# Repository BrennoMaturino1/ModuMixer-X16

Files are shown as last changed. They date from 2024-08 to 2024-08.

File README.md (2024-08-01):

# ModuMixer X16
ModuMixer is a modular digital audio mixer project with an almost unlimited amount of input and output channels (the limit is 65536)
It can be customized with input or output modules that are recognized by the "main computer"
The cue and main output signals are connected together in a summing amplifier configuration where each module sums it's signal to the data lines
The modules are digitally recognized by a custom protocol over USART where during boot one module is powered at a time and receives an address from the main computer (i know connecting multiple devices to USART isn't a good idea but i guess it will work), the digital signal processing works with an STM32 microcontroller for processing and a codec for digital to analog and analog to digital conversions

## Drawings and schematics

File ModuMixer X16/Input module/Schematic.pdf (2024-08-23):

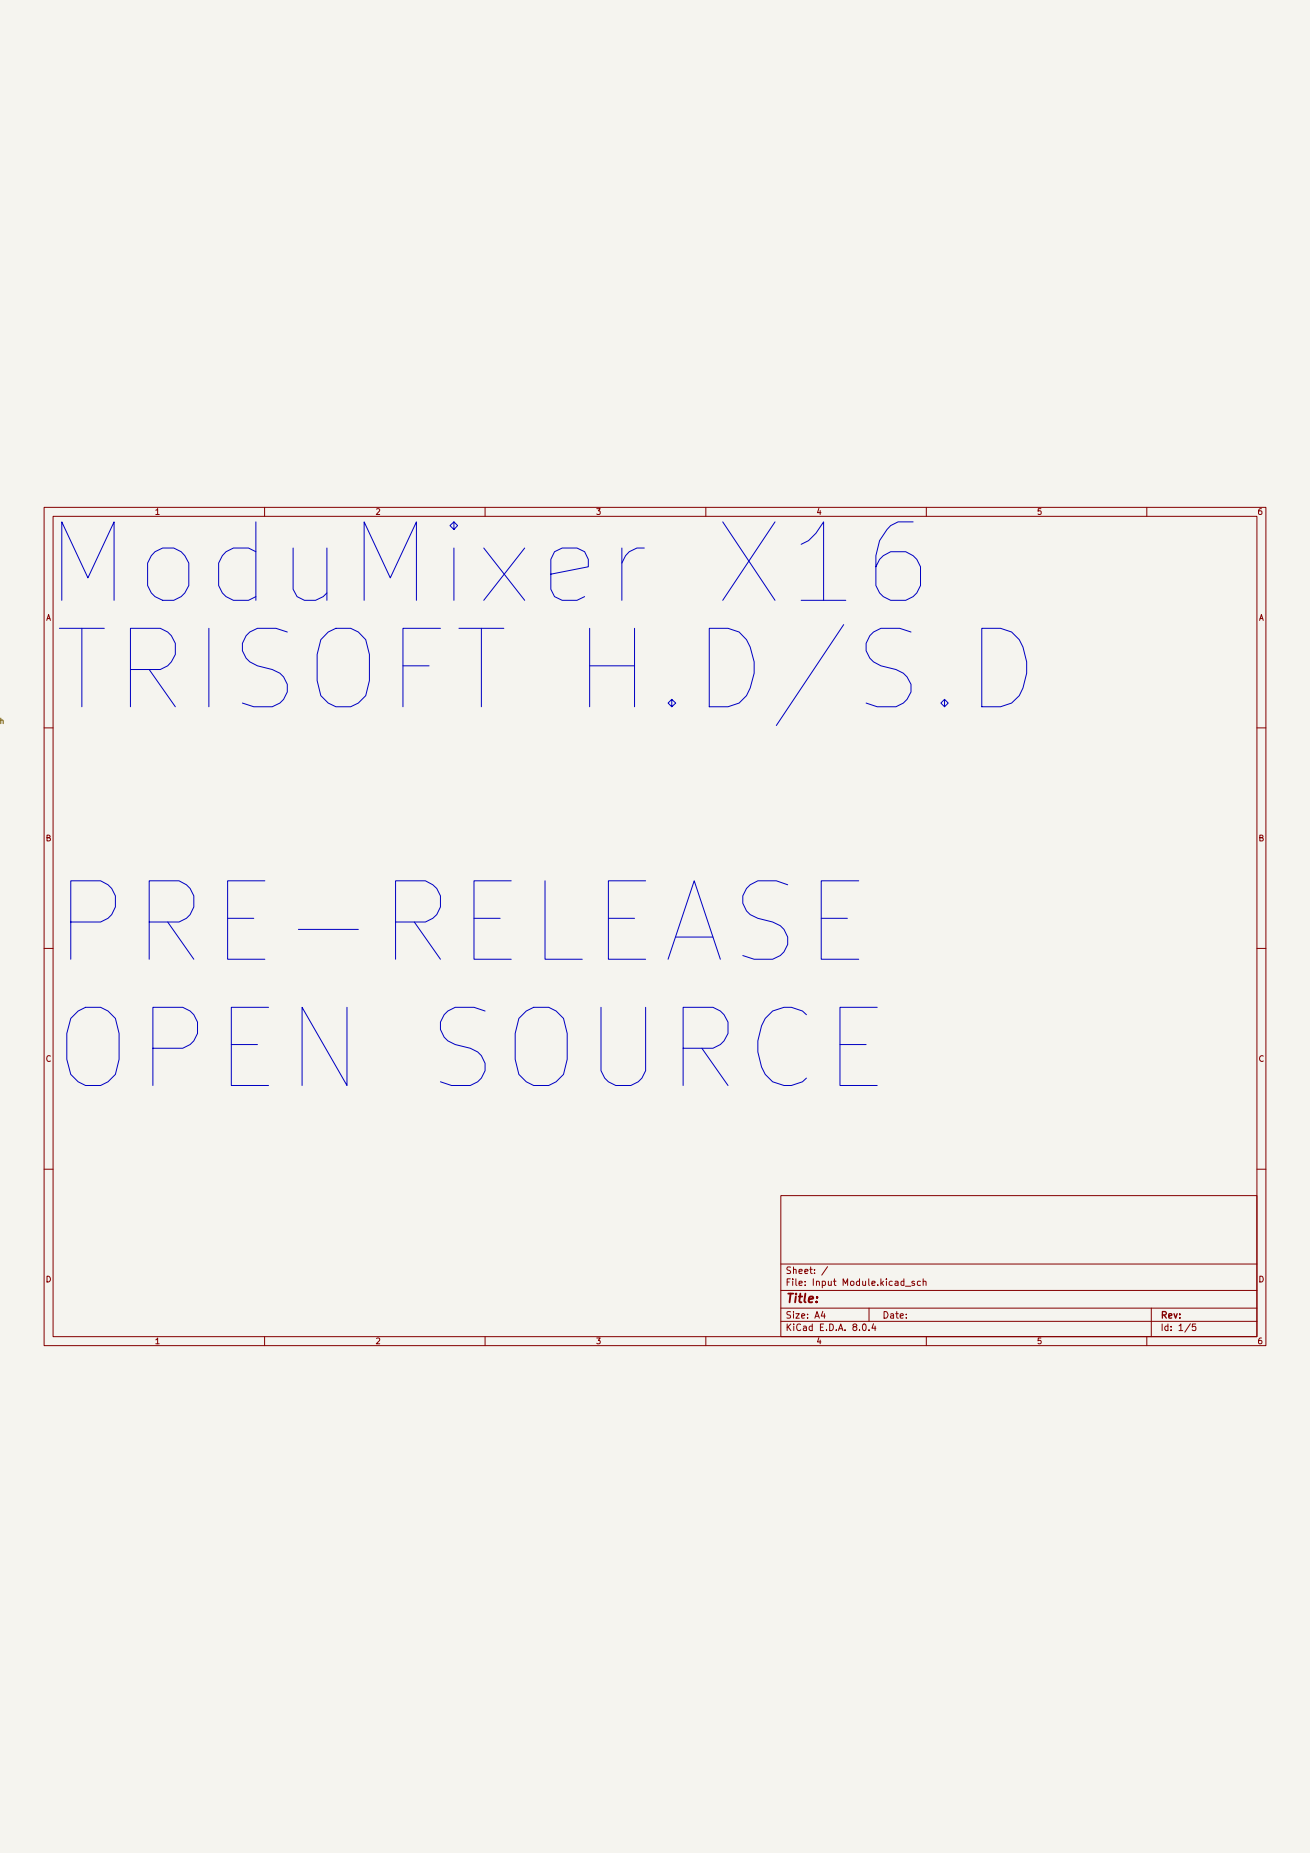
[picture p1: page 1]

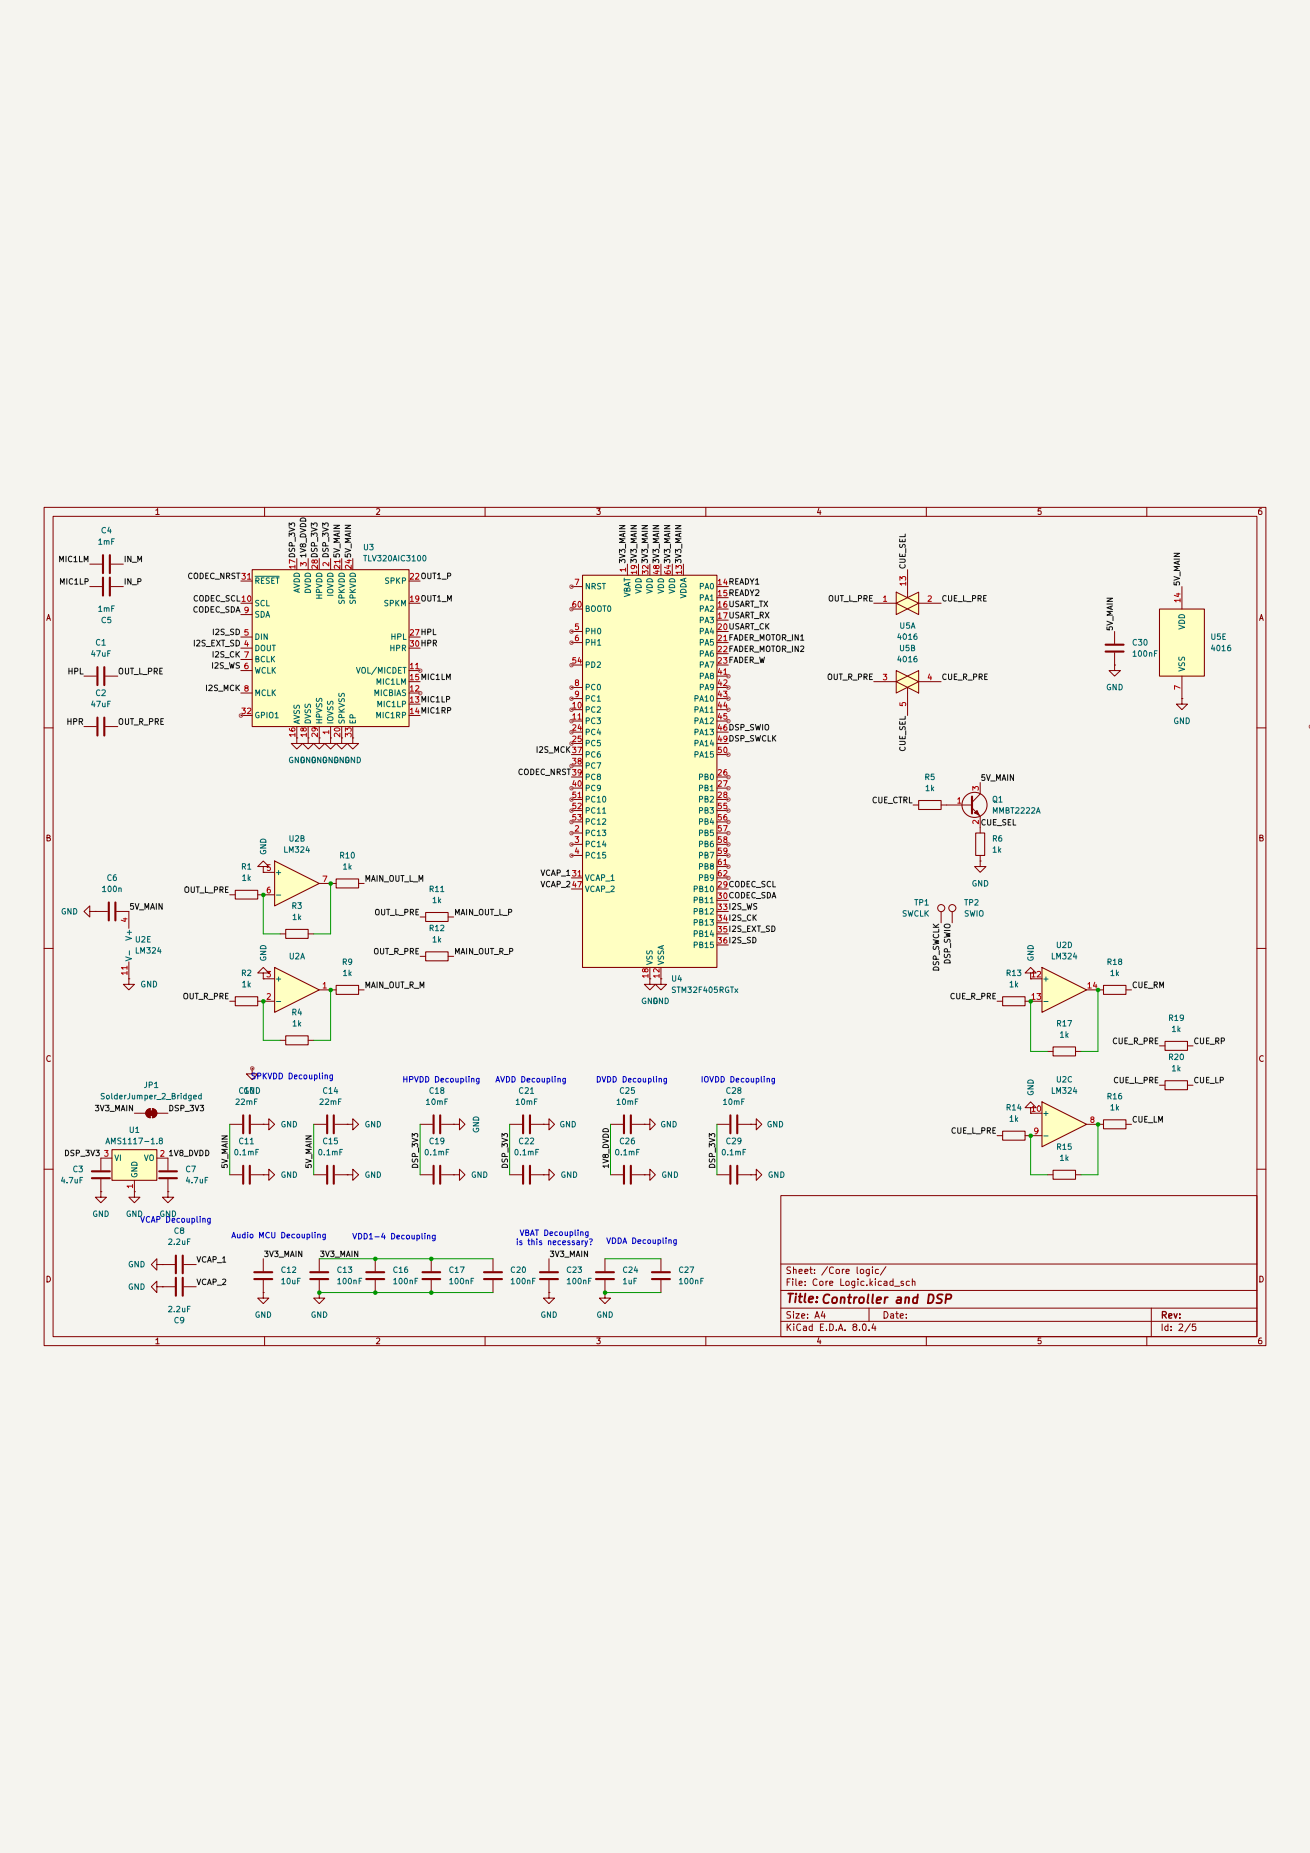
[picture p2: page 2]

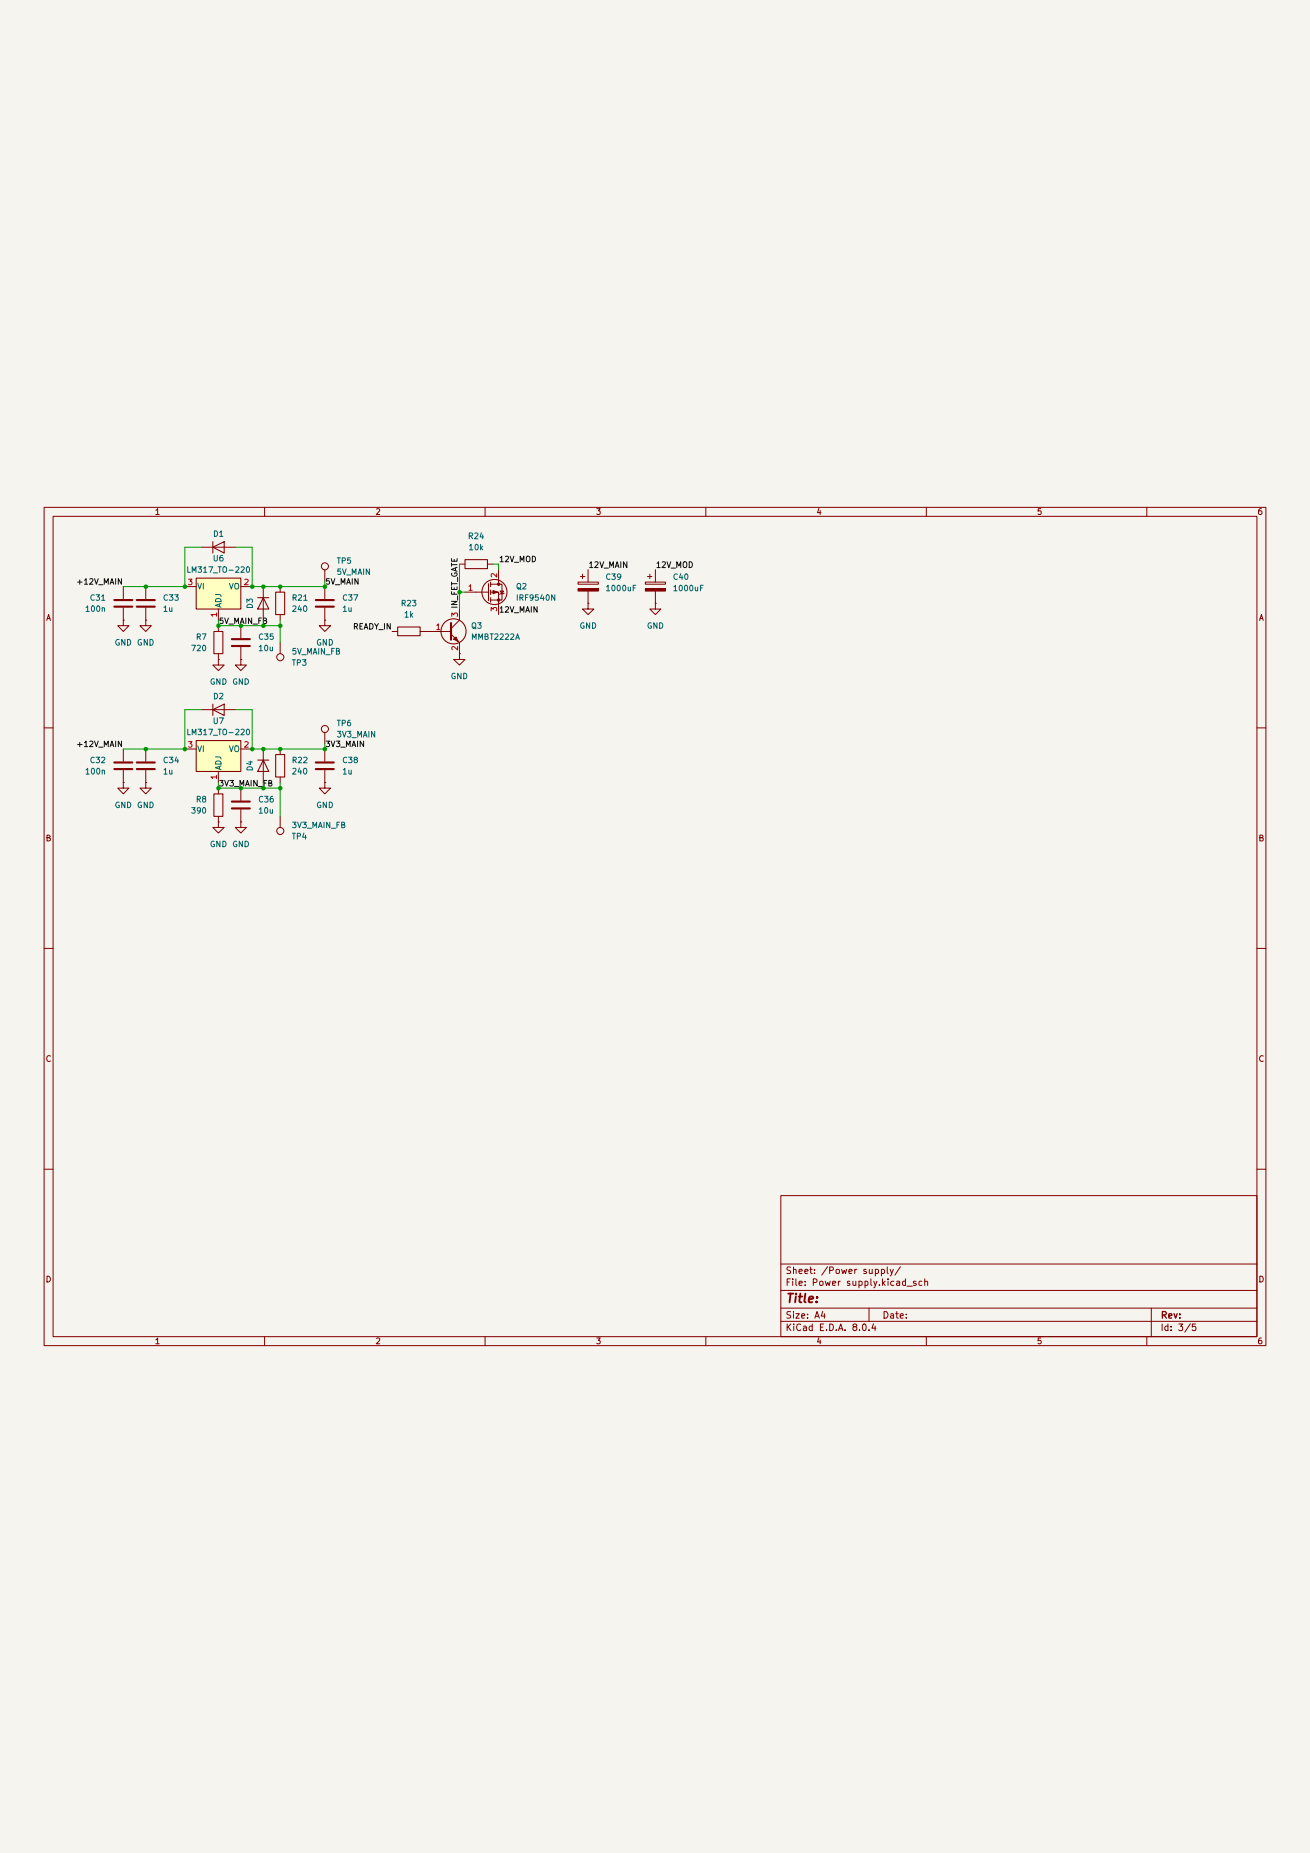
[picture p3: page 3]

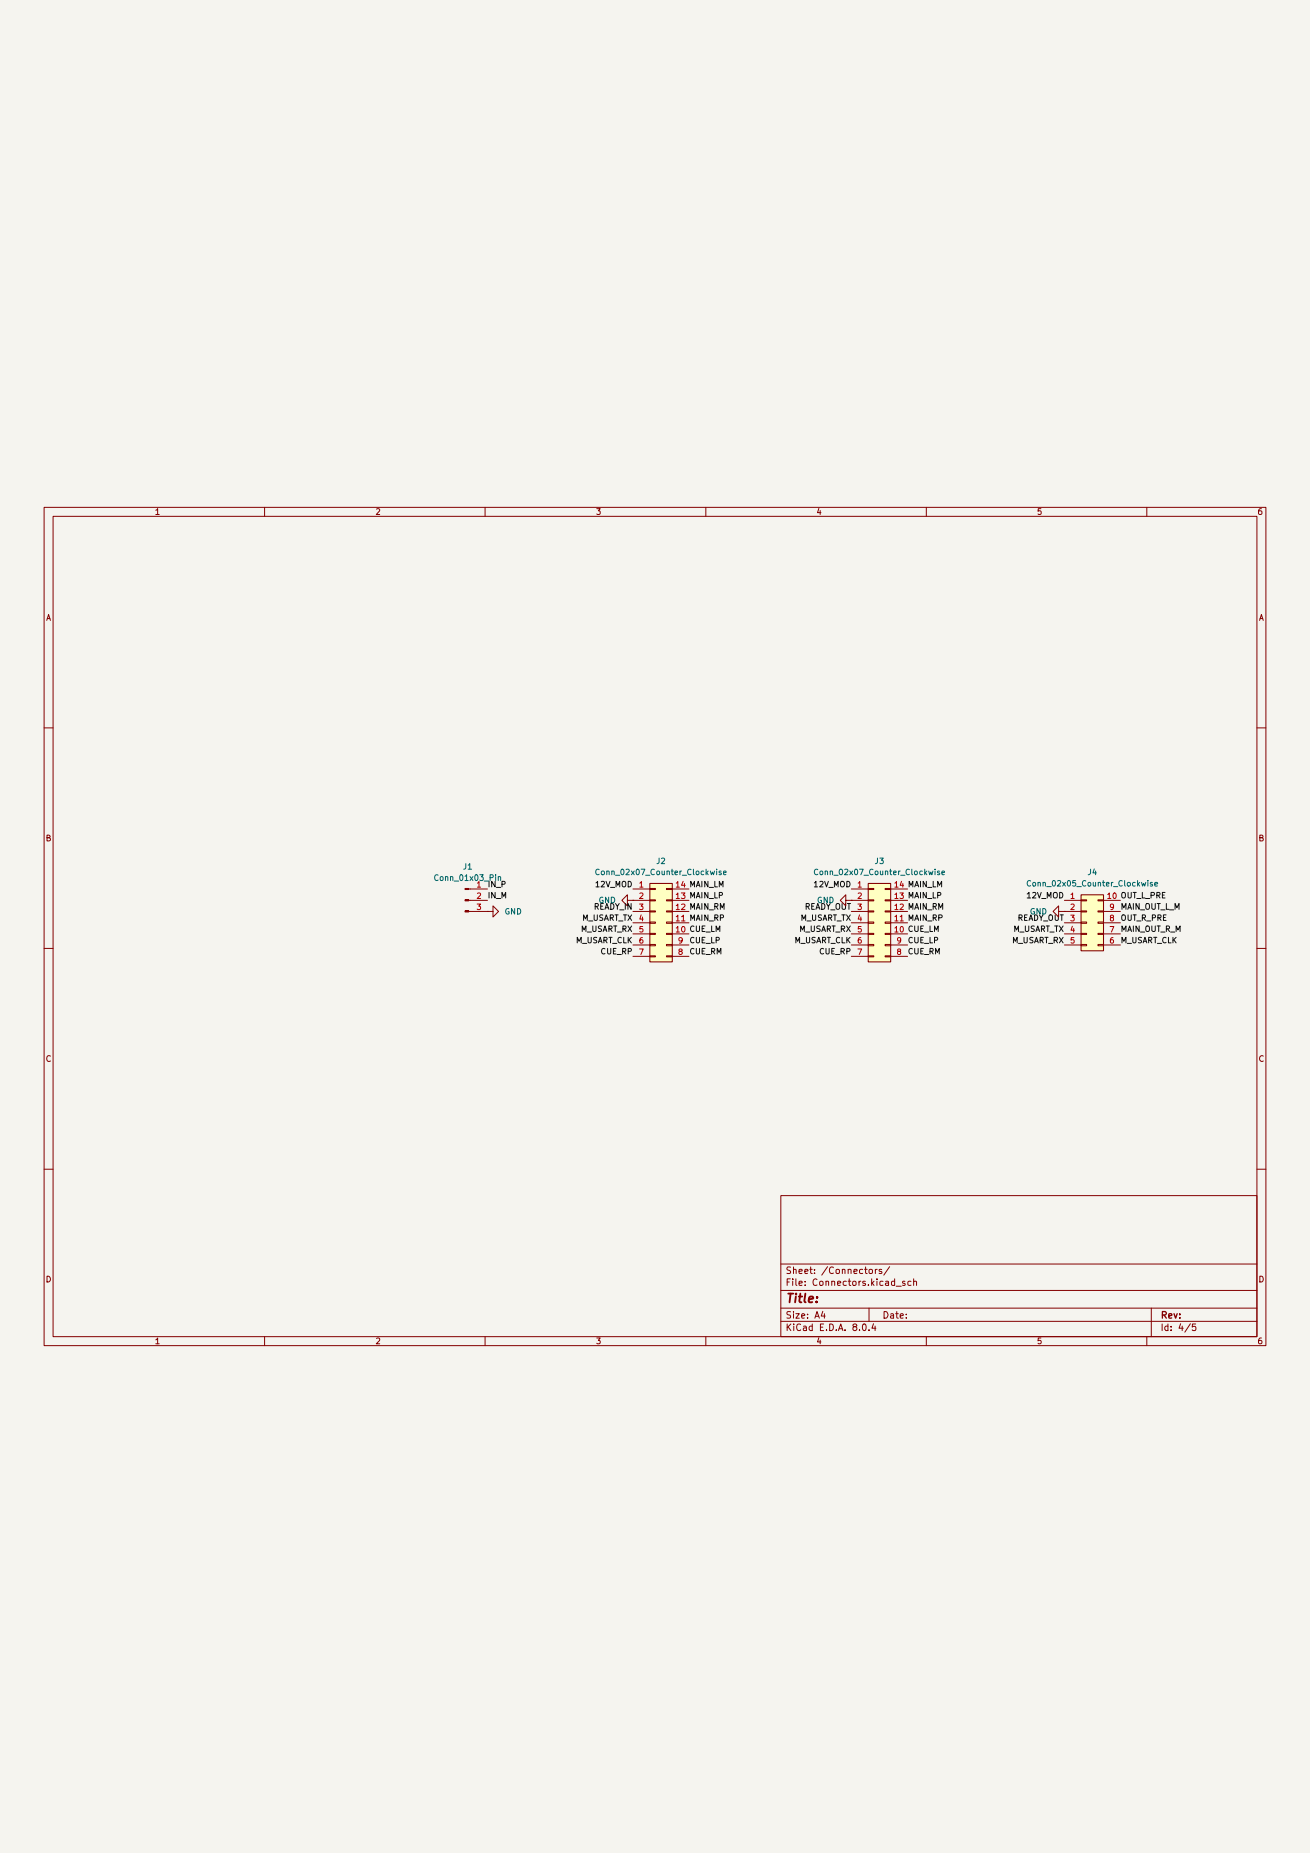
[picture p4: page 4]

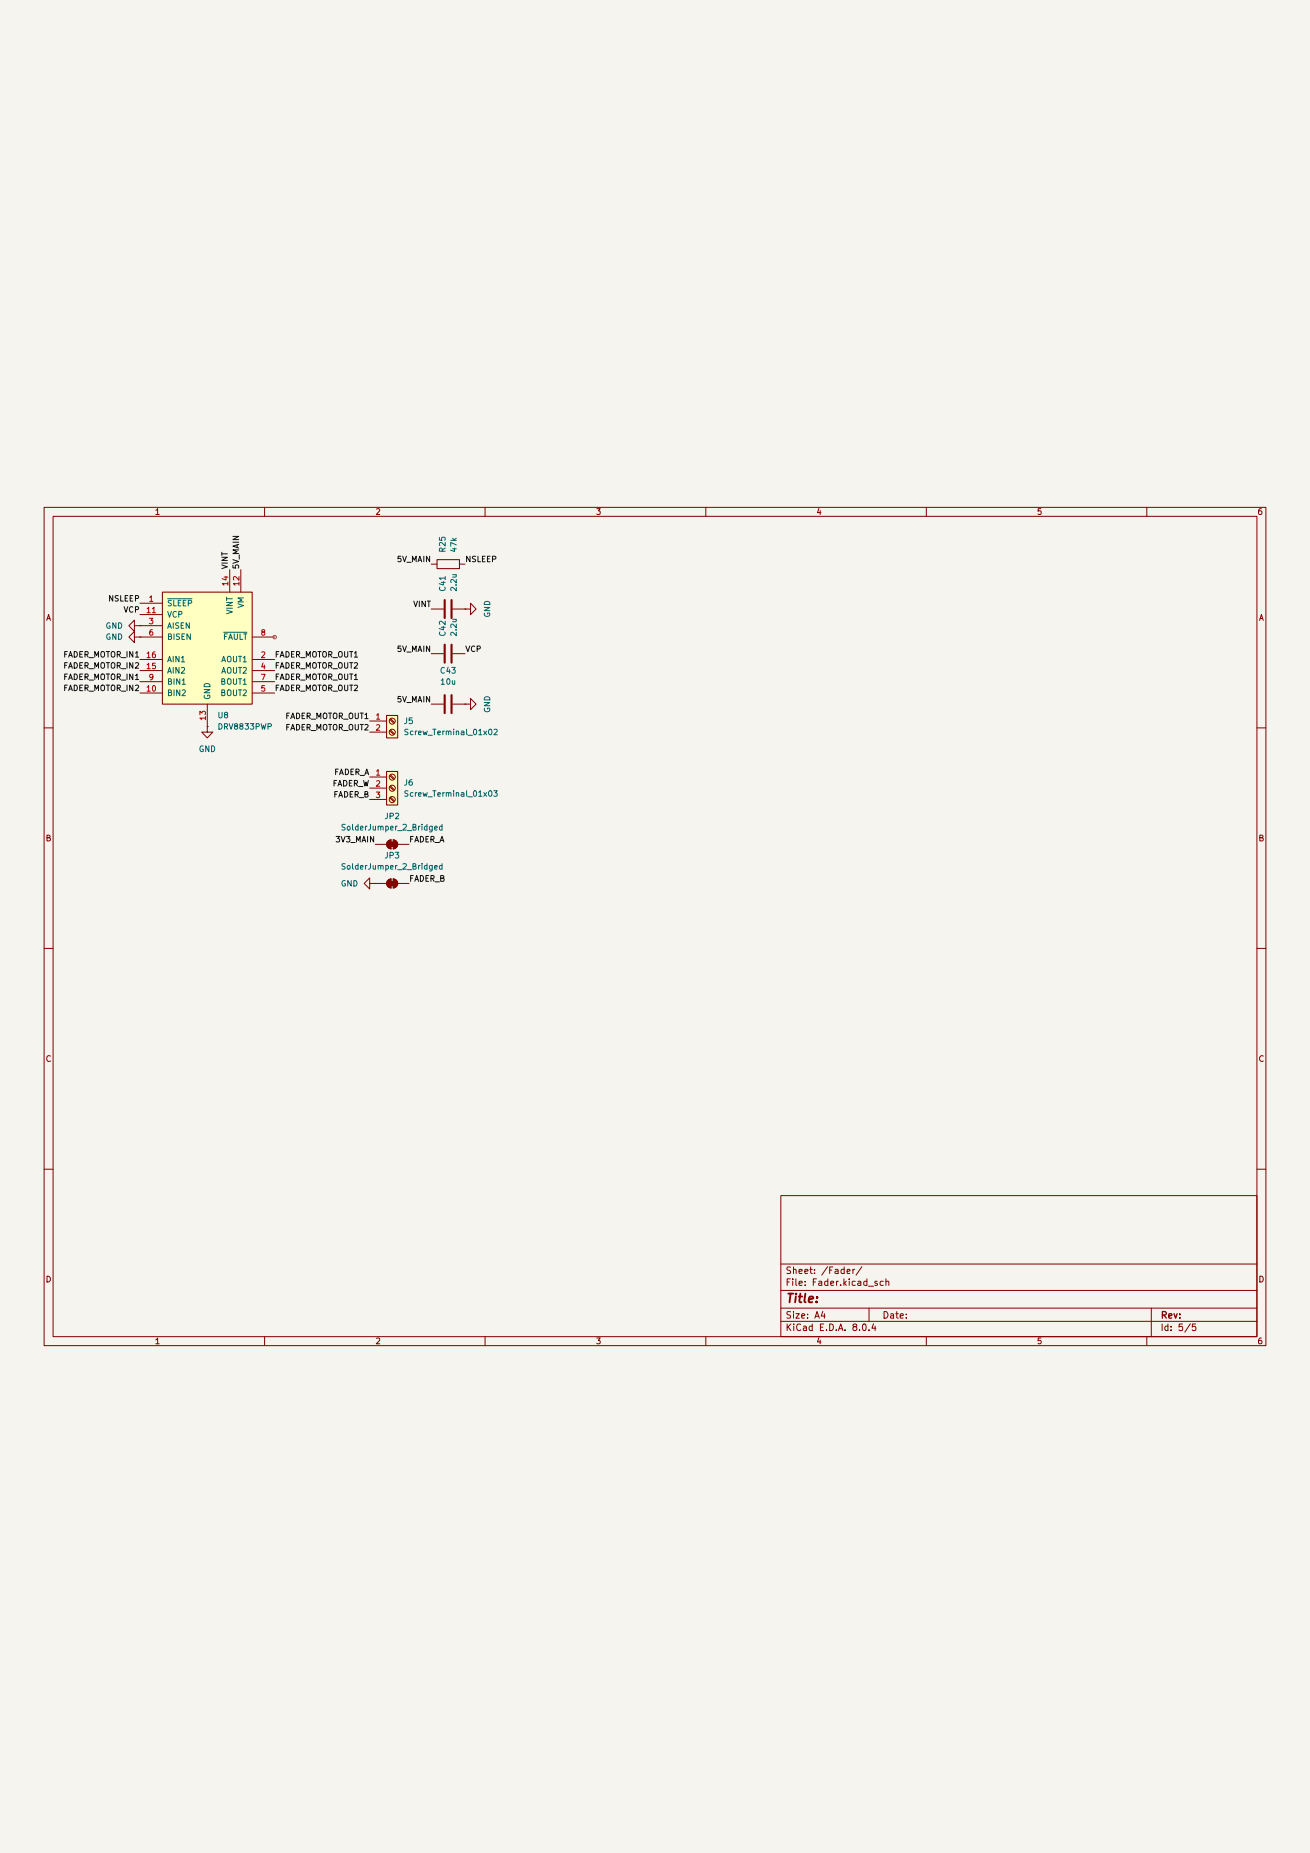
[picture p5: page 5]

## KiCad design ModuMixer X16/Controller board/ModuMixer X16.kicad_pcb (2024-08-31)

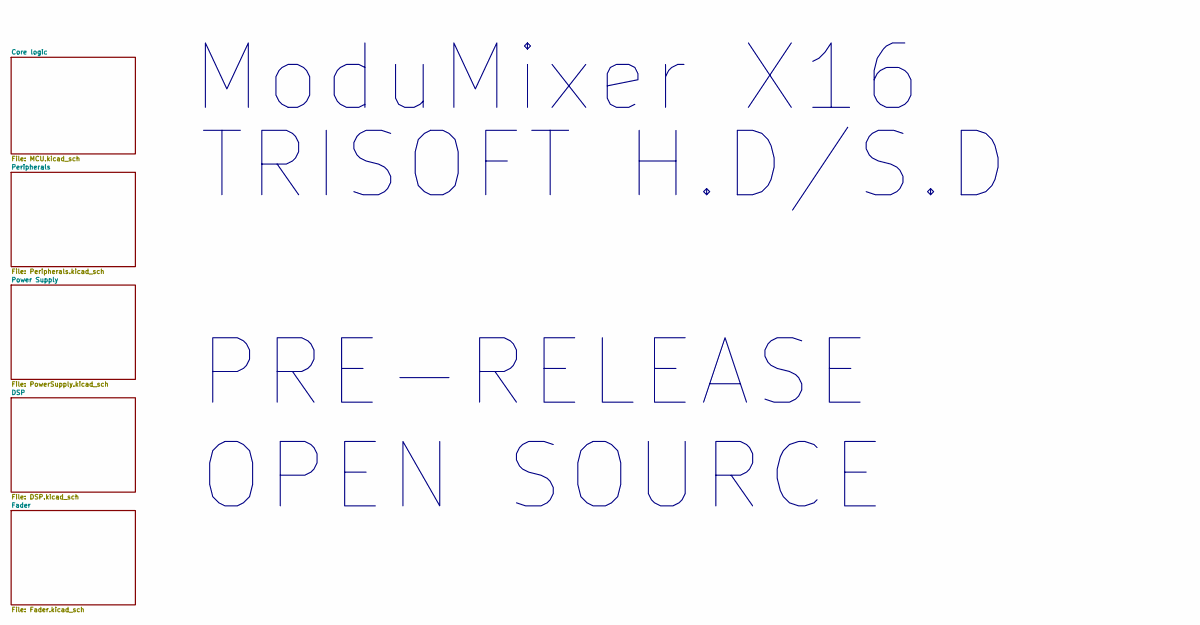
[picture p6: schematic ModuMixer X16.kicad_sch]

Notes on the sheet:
ModuMixer X16
TRISOFT H.D/S.D PRE-RELEASE OPEN SOURCE

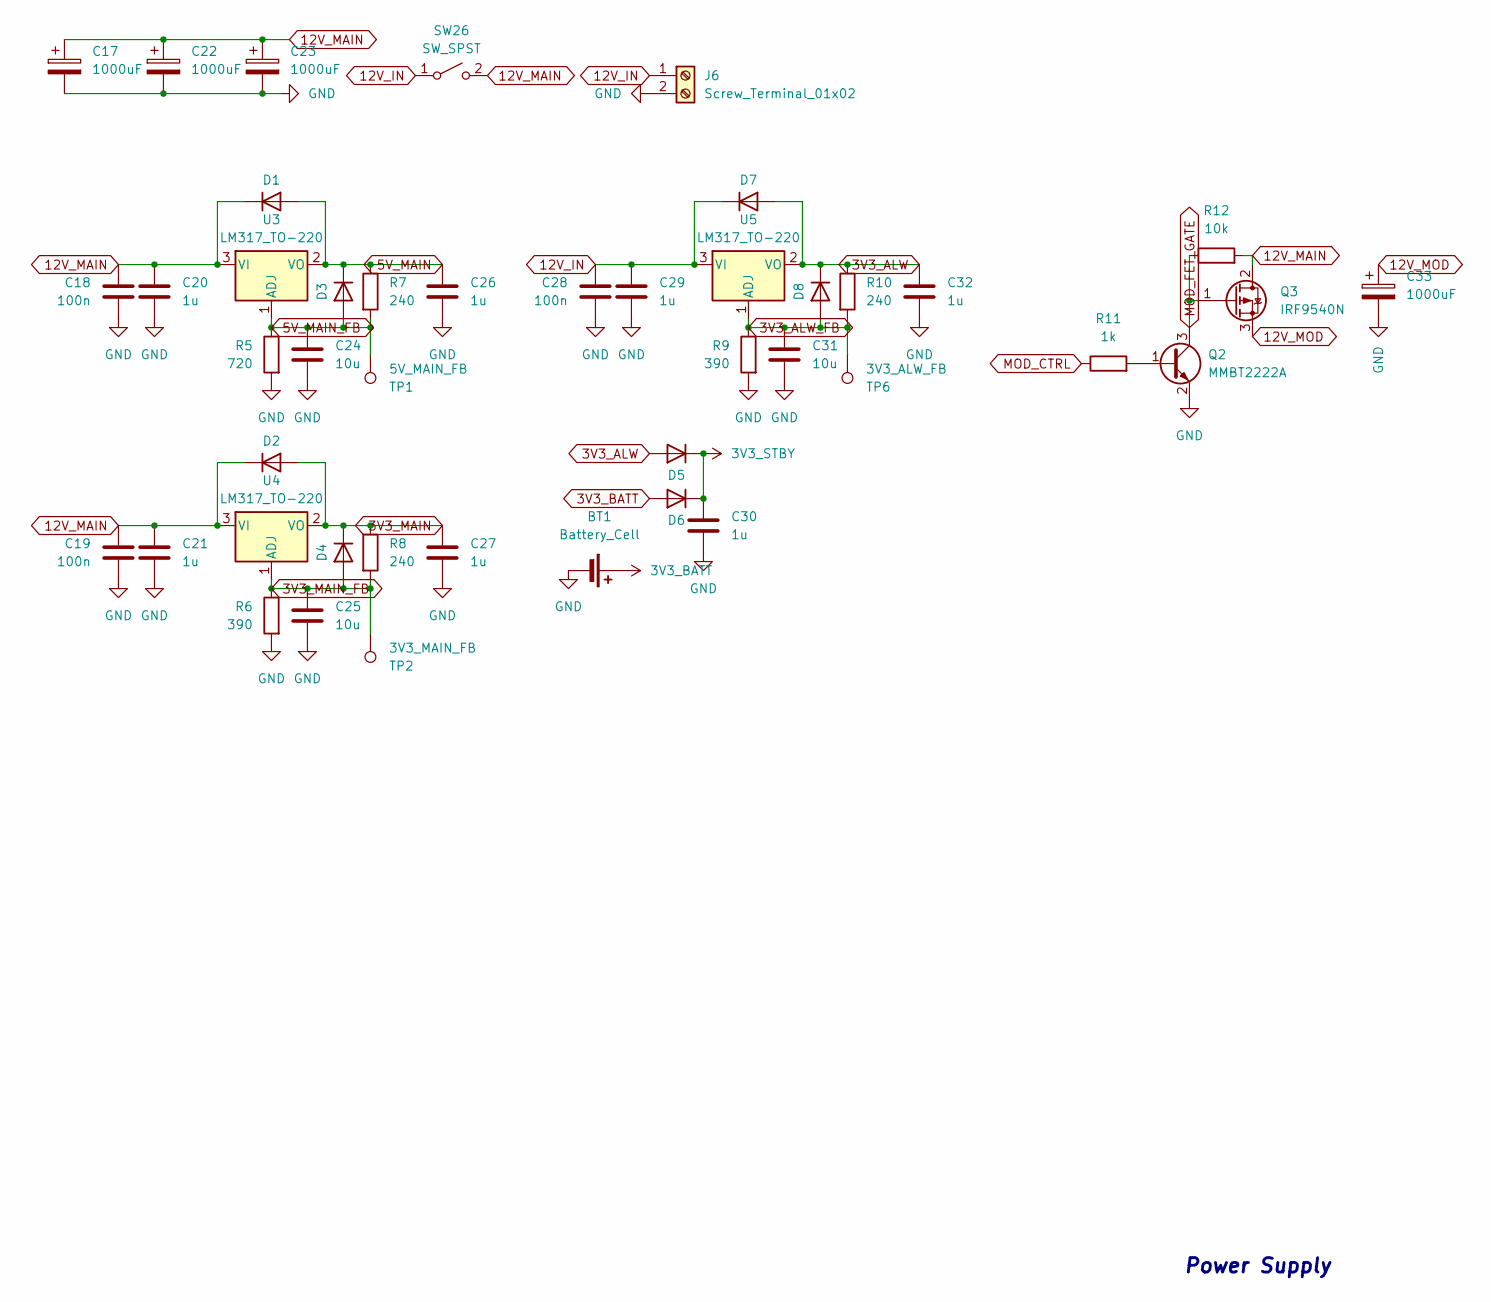
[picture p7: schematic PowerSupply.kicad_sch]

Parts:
BT1: Battery_Cell
C17, C22, C23, C33: 1000uF; CP_Elec_10x10
C18, C19, C28: 100n; C_0603_1608Metric
C20, C21, C26, C27, C29, C30, C32: 1u; C_0603_1608Metric
C24, C25, C31: 10u; C_0603_1608Metric
D1, D2, D3, D4, D5, D6, D7, D8: D_SOD-123
J6: Screw_Terminal_01x02; TerminalBlock_Xinya_XY308-2.54-2P_1x02_P2.54mm_Horizontal
Q2: MMBT2222A; SOT-23
Q3: IRF9540N; TO-220-3_Vertical
R5: 720; R_0603_1608Metric
R6, R9: 390; R_0603_1608Metric
R7, R8, R10: 240; R_0603_1608Metric
R11: 1k; R_0603_1608Metric
R12: 10k; R_0603_1608Metric
SW26: SW_SPST; TerminalBlock_Xinya_XY308-2.54-2P_1x02_P2.54mm_Horizontal
TP1: 5V_MAIN_FB; TestPoint_Pad_D3.0mm
TP2: 3V3_MAIN_FB; TestPoint_Pad_D3.0mm
TP6: 3V3_ALW_FB; TestPoint_Pad_D3.0mm
U3, U4, U5: LM317_TO-220; TO-220-3_Vertical

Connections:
3V3_ALW: C32.1, D5.2 (A), D7.2 (A), D8.1 (K), R10.1, U5.2 (VO)
3V3_ALW_FB: C31.1, D8.2 (A), R9.1, R10.2, TP6.1, U5.1 (ADJ)
3V3_BATT: D6.2 (A)
3V3_MAIN: C27.1, D2.2 (A), D4.1 (K), R8.1, U4.2 (VO); also elsewhere on the board
3V3_MAIN_FB: C25.1, D4.2 (A), R6.1, R8.2, TP2.1, U4.1 (ADJ)
3V3_STBY: C30.1, D5.1 (K), D6.1 (K); also elsewhere on the board
5V_MAIN: C26.1, D1.2 (A), D3.1 (K), R7.1, U3.2 (VO); also elsewhere on the board
5V_MAIN_FB: C24.1, D3.2 (A), R5.1, R7.2, TP1.1, U3.1 (ADJ)
12V_IN: C28.1, C29.1, D7.1 (K), J6.1, SW26.1 (A), U5.3 (VI)
12V_MAIN: C17.1, C18.1, C19.1, C20.1, C21.1, C22.1, C23.1, D1.1 (K), D2.1 (K), Q3.2 (D), R12.2, SW26.2 (B), U3.3 (VI), U4.3 (VI)
12V_MOD: C33.1, Q3.3 (S); also elsewhere on the board
GND: BT1.2 (-), C17.2, C18.2, C19.2, C20.2, C21.2, C22.2, C23.2, C24.2, C25.2, C26.2, C27.2, C28.2, C29.2, C30.2, C31.2, C32.2, C33.2, J6.2, Q2.2 (E), R5.2, R6.2, R9.2; also elsewhere on the board
MOD_CTRL: R11.1; also elsewhere on the board
MOD_FET_GATE: Q2.3 (C), Q3.1 (G), R12.1
unnamed: Q2.1 (B), R11.2

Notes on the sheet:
Power Supply

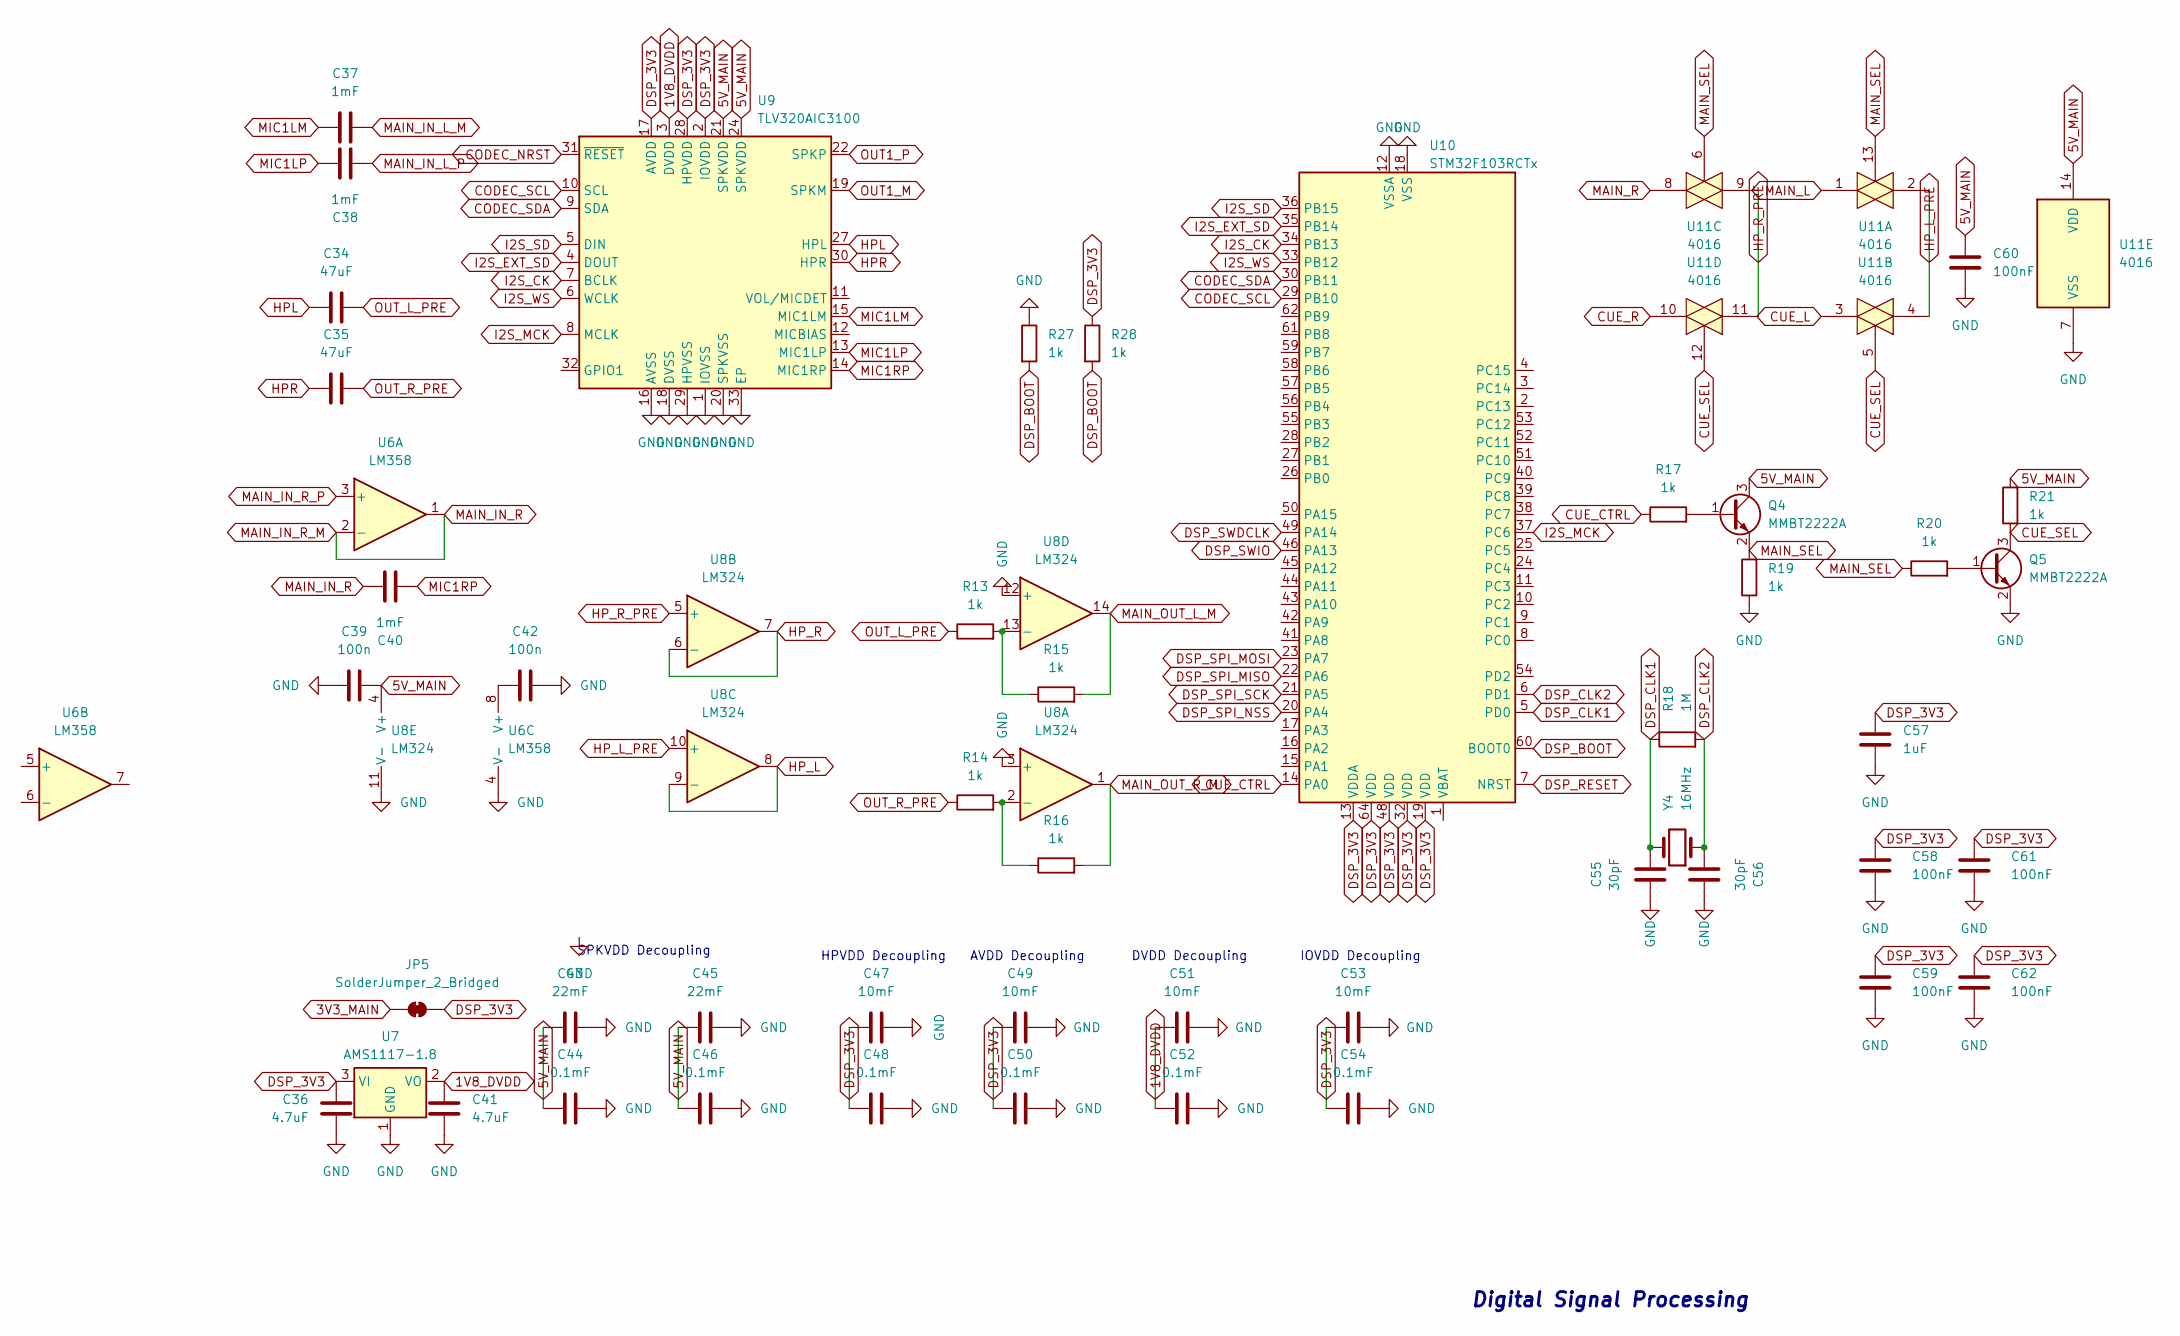
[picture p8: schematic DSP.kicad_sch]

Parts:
C34, C35: 47uF; C_0603_1608Metric
C36, C41: 4.7uF; C_0603_1608Metric
C37, C38, C40: 1mF; C_0603_1608Metric
C39, C42: 100n; C_0603_1608Metric
C43, C45: 22mF; C_0603_1608Metric
C44, C46, C48, C50, C52, C54: 0.1mF; C_0603_1608Metric
C47, C49, C51, C53: 10mF; C_0603_1608Metric
C55, C56: 30pF; C_0603_1608Metric
C57: 1uF; C_0603_1608Metric
C58, C59, C60, C61, C62: 100nF; C_0603_1608Metric
JP5: SolderJumper_2_Bridged; SolderJumper-2_P1.3mm_Bridged2Bar_Pad1.0x1.5mm
Q4, Q5: MMBT2222A; SOT-23
R13, R14, R15, R16, R17, R19, R20, R21, R27, R28: 1k; R_0603_1608Metric
R18: 1M; R_0603_1608Metric
U6: LM358; LFCSP-8_2x2mm_P0.5mm
U7: AMS1117-1.8; SOT-223-3_TabPin2
U8: LM324; SOIC-14_3.9x8.7mm_P1.27mm
U9: TLV320AIC3100; VQFN-32-1EP_5x5mm_P0.5mm_EP3.5x3.5mm
U10: STM32F103RCTx; LQFP-64_10x10mm_P0.5mm
U11: 4016; SOIC-14_3.9x8.7mm_P1.27mm
Y4: 16MHz; Crystal_HC49-U_Vertical

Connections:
1V8_DVDD: C41.2, C51.1, C52.1, U7.2 (VO), U9.3 (DVDD)
3V3_MAIN: JP5.1 (A); also elsewhere on the board
5V_MAIN: C39.2, C43.1, C44.1, C45.1, C46.1, C60.1, Q4.3 (C), R21.2, U8.4 (V+), U9.21 (SPKVDD), U9.24 (SPKVDD), U11.14 (VDD); also elsewhere on the board
CODEC_NRST: U9.31 (~RESET)
CODEC_SCL: U9.10 (SCL), U10.29 (PB10)
CODEC_SDA: U9.9 (SDA), U10.30 (PB11)
CUE_CTRL: R17.1, U10.14 (PA0)
CUE_L: U11.3
CUE_R: U11.10
CUE_SEL: Q5.3 (C), R21.1, U11.5, U11.12
DSP_3V3: C36.2, C47.1, C48.1, C49.1, C50.1, C53.1, C54.1, C57.1, C58.1, C59.1, C61.1, C62.1, JP5.2 (B), R28.1, U7.3 (VI), U9.2 (IOVDD), U9.17 (AVDD), U9.28 (HPVDD), U10.13 (VDDA), U10.19 (VDD), U10.32 (VDD), U10.48 (VDD), U10.64 (VDD)
DSP_BOOT: R27.2, R28.2, U10.60 (BOOT0); also elsewhere on the board
DSP_CLK1: C55.1, R18.1, U10.5 (PD0), Y4.2
DSP_CLK2: C56.1, R18.2, U10.6 (PD1), Y4.1
DSP_RESET: U10.7 (NRST); also elsewhere on the board
DSP_SPI_MISO: U10.22 (PA6)
DSP_SPI_MOSI: U10.23 (PA7)
DSP_SPI_NSS: U10.20 (PA4)
DSP_SPI_SCK: U10.21 (PA5)
DSP_SWDCLK: U10.49 (PA14); also elsewhere on the board
DSP_SWIO: U10.46 (PA13); also elsewhere on the board
GND: C36.1, C39.1, C41.1, C42.2, C43.2, C44.2, C45.2, C46.2, C47.2, C48.2, C49.2, C50.2, C51.2, C52.2, C53.2, C54.2, C55.2, C56.2, C57.2, C58.2, C59.2, C60.2, C61.2, C62.2, Q5.2 (E), R19.1, R27.1, U6.4 (V-), U7.1 (GND), U8.3 (+), U8.11 (V-), U8.12 (+), U9.1 (IOVSS), U9.16 (AVSS), U9.18 (DVSS), U9.20 (SPKVSS), U9.25 (SPKVSS), U9.29 (HPVSS), U9.33 (EP), U10.12 (VSSA), U10.18 (VSS), U10.31 (VSS), U10.47 (VSS), U10.63 (VSS), U11.7 (VSS); also elsewhere on the board
HPL: C34.1, U9.27 (HPL)
HPR: C35.1, U9.30 (HPR)
HP_L: U8.8, U8.9 (-); also elsewhere on the board
HP_L_PRE: U8.10 (+), U11.2, U11.4
HP_R: U8.6 (-), U8.7; also elsewhere on the board
HP_R_PRE: U8.5 (+), U11.9, U11.11
I2S_CK: U9.7 (BCLK), U10.34 (PB13)
I2S_EXT_SD: U9.4 (DOUT), U10.35 (PB14)
I2S_MCK: U9.8 (MCLK), U10.37 (PC6)
I2S_SD: U9.5 (DIN), U10.36 (PB15)
I2S_WS: U9.6 (WCLK), U10.33 (PB12)
MAIN_IN_L_M: C37.2
MAIN_IN_L_P: C38.2
MAIN_IN_R: C40.2, U6.1, U6.2 (-)
MAIN_IN_R_P: U6.3 (+)
MAIN_L: U11.1
MAIN_OUT_L_M: R15.2, U8.14; also elsewhere on the board
MAIN_OUT_R_M: R16.2, U8.1; also elsewhere on the board
MAIN_R: U11.8
MAIN_SEL: Q4.2 (E), R19.2, R20.1, U11.6, U11.13
MIC1LM: C37.1, U9.15 (MIC1LM)
MIC1LP: C38.1, U9.13 (MIC1LP)
MIC1RP: C40.1, U9.14 (MIC1RP)
unnamed: Q4.1 (B), R17.2
unnamed: Q5.1 (B), R20.2
unnamed: C42.1, U6.8 (V+)
unnamed: R14.2, R16.1, U8.2 (-)
unnamed: R13.2, R15.1, U8.13 (-)
OUT1_M: U9.19 (SPKM), U9.23 (SPKM)
OUT1_P: U9.22 (SPKP), U9.26 (SPKP)
OUT_L_PRE: C34.2, R13.1; also elsewhere on the board
OUT_R_PRE: C35.2, R14.1; also elsewhere on the board

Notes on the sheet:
DVDD Decoupling
IOVDD Decoupling
Digital Signal Processing
HPVDD Decoupling
AVDD Decoupling
SPKVDD Decoupling

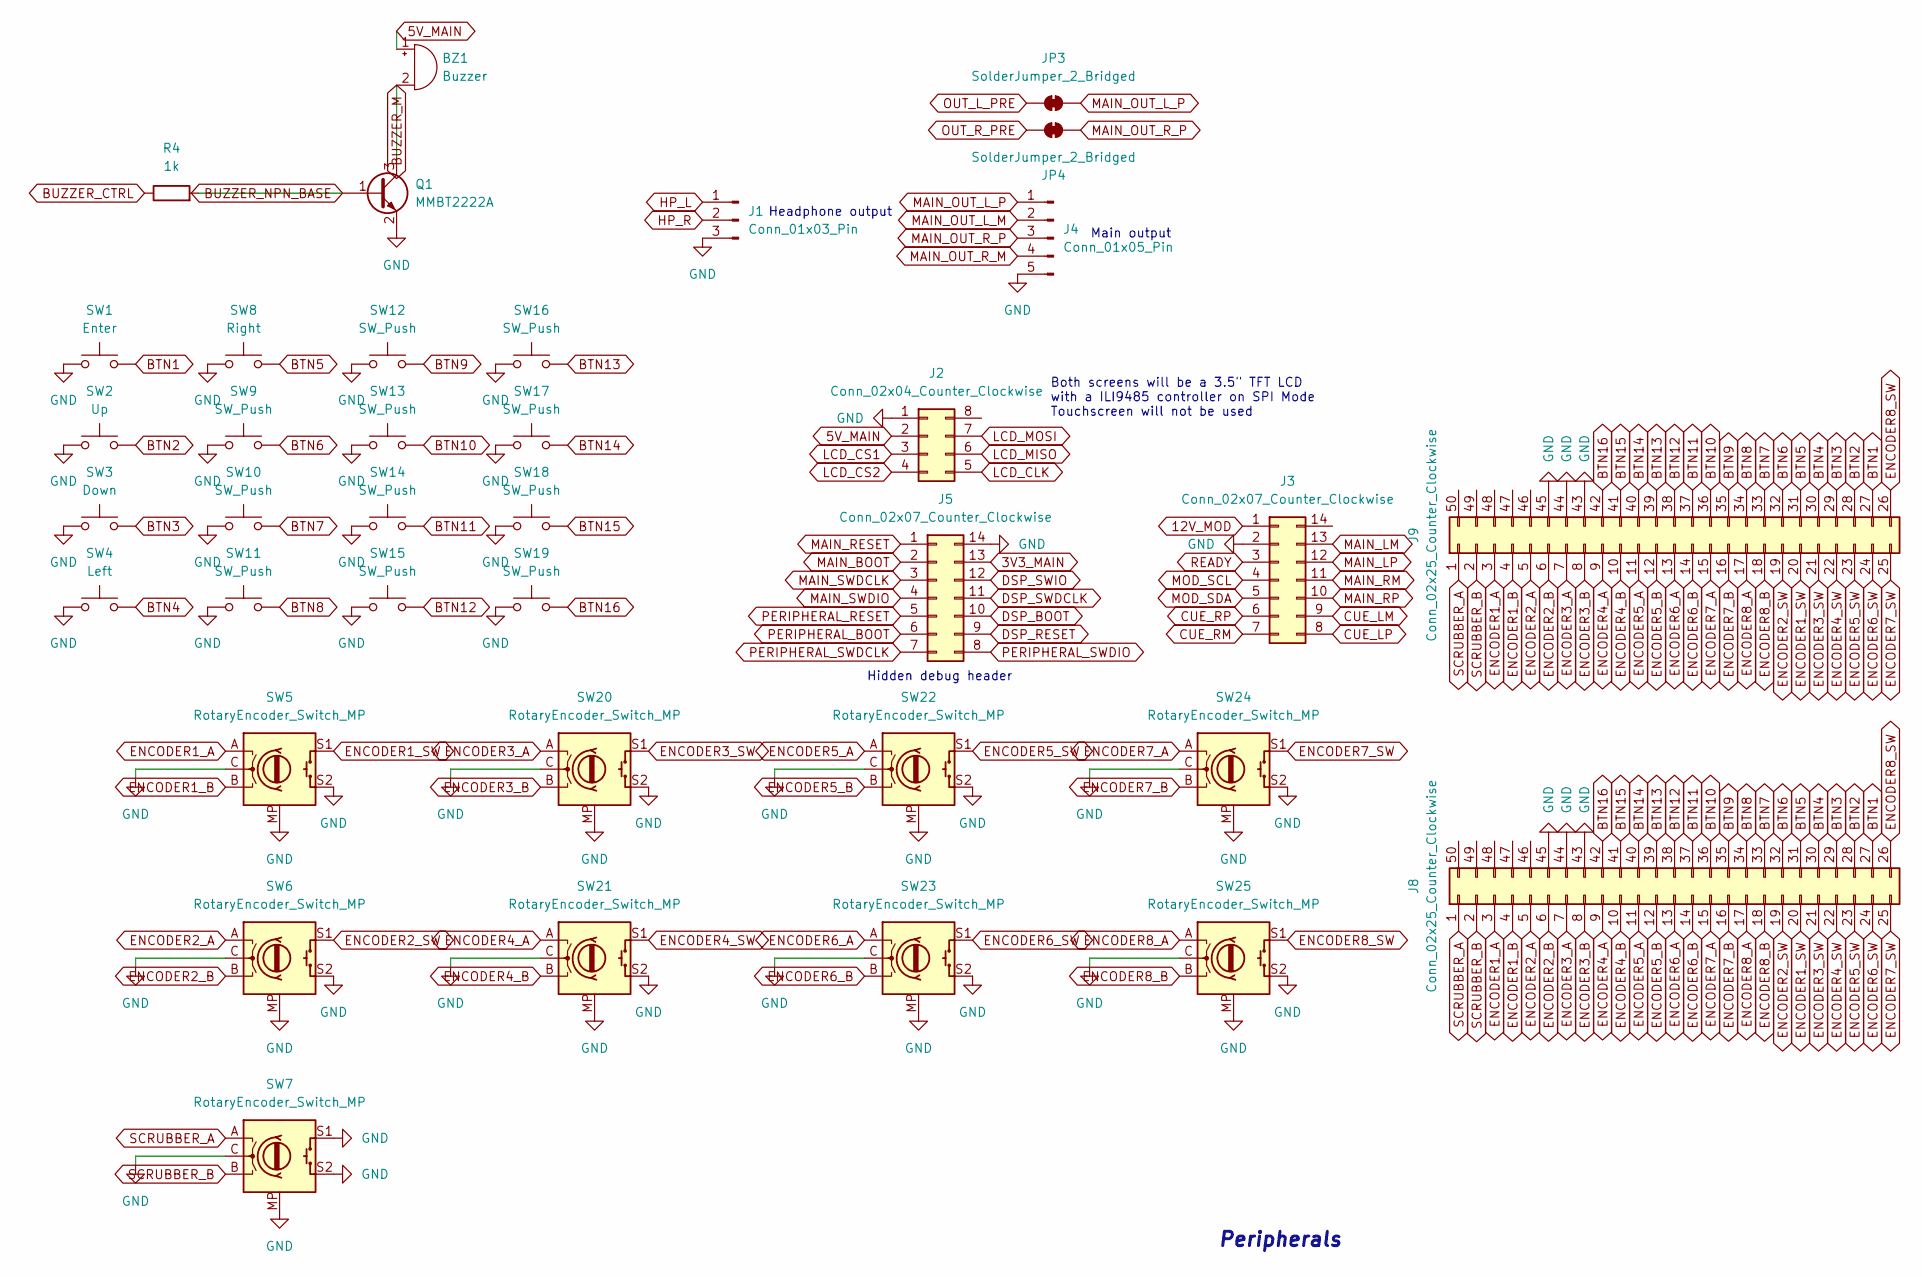
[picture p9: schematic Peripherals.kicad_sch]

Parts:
BZ1: Buzzer; Buzzer_12x9.5RM7.6
J1: Conn_01x03_Pin; PinHeader_1x03_P2.54mm_Vertical
J2: Conn_02x04_Counter_Clockwise; PinSocket_2x04_P2.54mm_Vertical
J3, J5: Conn_02x07_Counter_Clockwise; IDC-Header_2x07_P2.54mm_Vertical
J4: Conn_01x05_Pin; PinSocket_1x05_P2.54mm_Vertical
J8, J9: Conn_02x25_Counter_Clockwise; IDC-Header_2x25_P2.54mm_Vertical
JP3, JP4: SolderJumper_2_Bridged; SolderJumper-2_P1.3mm_Bridged2Bar_Pad1.0x1.5mm
Q1: MMBT2222A; SOT-23
R4: 1k; R_0603_1608Metric
SW1: Enter; SW_SPST_B3S-1000
SW2: Up; SW_SPST_B3S-1000
SW3: Down; SW_SPST_B3S-1000
SW4: Left; SW_SPST_B3S-1000
SW5, SW6, SW7, SW20, SW21, SW22, SW23, SW24, SW25: RotaryEncoder_Switch_MP; RotaryEncoder_Alps_EC11E-Switch_Vertical_H20mm
SW8: Right; SW_SPST_B3S-1000
SW9, SW10, SW11, SW12, SW13, SW14, SW15, SW16, SW17, SW18, SW19: SW_Push; SW_SPST_B3S-1000

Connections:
3V3_MAIN: J5.13; also elsewhere on the board
5V_MAIN: BZ1.1 (+), J2.2; also elsewhere on the board
12V_MOD: J3.1; also elsewhere on the board
BTN1: J8.27, J9.27, SW1.2; also elsewhere on the board
BTN2: J8.28, J9.28, SW2.2; also elsewhere on the board
BTN3: J8.29, J9.29, SW3.2; also elsewhere on the board
BTN4: J8.30, J9.30, SW4.2; also elsewhere on the board
BTN5: J8.31, J9.31, SW8.2; also elsewhere on the board
BTN6: J8.32, J9.32, SW9.2; also elsewhere on the board
BTN7: J8.33, J9.33, SW10.2; also elsewhere on the board
BTN8: J8.34, J9.34, SW11.2; also elsewhere on the board
BTN9: J8.35, J9.35, SW12.2; also elsewhere on the board
BTN10: J8.36, J9.36, SW13.2; also elsewhere on the board
BTN11: J8.37, J9.37, SW14.2; also elsewhere on the board
BTN12: J8.38, J9.38, SW15.2; also elsewhere on the board
BTN13: J8.39, J9.39, SW16.2; also elsewhere on the board
BTN14: J8.40, J9.40, SW17.2; also elsewhere on the board
BTN15: J8.41, J9.41, SW18.2; also elsewhere on the board
BTN16: J8.42, J9.42, SW19.2; also elsewhere on the board
BUZZER_CTRL: R4.1; also elsewhere on the board
BUZZER_M: BZ1.2 (-), Q1.3 (C)
BUZZER_NPN_BASE: Q1.1 (B), R4.2
CUE_LM: J3.9
CUE_LP: J3.8
CUE_RM: J3.7
CUE_RP: J3.6
DSP_BOOT: J5.10; also elsewhere on the board
DSP_RESET: J5.9; also elsewhere on the board
DSP_SWDCLK: J5.11; also elsewhere on the board
DSP_SWIO: J5.12; also elsewhere on the board
ENCODER1_A: J8.3, J9.3, SW5.A; also elsewhere on the board
ENCODER1_B: J8.4, J9.4, SW5.B; also elsewhere on the board
ENCODER1_SW: J8.20, J9.20, SW5.S1; also elsewhere on the board
ENCODER2_A: J8.5, J9.5, SW6.A; also elsewhere on the board
ENCODER2_B: J8.6, J9.6, SW6.B; also elsewhere on the board
ENCODER2_SW: J8.19, J9.19, SW6.S1; also elsewhere on the board
ENCODER3_A: J8.7, J9.7, SW20.A; also elsewhere on the board
ENCODER3_B: J8.8, J9.8, SW20.B; also elsewhere on the board
ENCODER3_SW: J8.21, J9.21, SW20.S1; also elsewhere on the board
ENCODER4_A: J8.9, J9.9, SW21.A; also elsewhere on the board
ENCODER4_B: J8.10, J9.10, SW21.B; also elsewhere on the board
ENCODER4_SW: J8.22, J9.22, SW21.S1; also elsewhere on the board
ENCODER5_A: J8.11, J9.11, SW22.A; also elsewhere on the board
ENCODER5_B: J8.12, J9.12, SW22.B; also elsewhere on the board
ENCODER5_SW: J8.23, J9.23, SW22.S1; also elsewhere on the board
ENCODER6_A: J8.13, J9.13, SW23.A; also elsewhere on the board
ENCODER6_B: J8.14, J9.14, SW23.B; also elsewhere on the board
ENCODER6_SW: J8.24, J9.24, SW23.S1; also elsewhere on the board
ENCODER7_A: J8.15, J9.15, SW24.A; also elsewhere on the board
ENCODER7_B: J8.16, J9.16, SW24.B; also elsewhere on the board
ENCODER7_SW: J8.25, J9.25, SW24.S1; also elsewhere on the board
ENCODER8_A: J8.17, J9.17, SW25.A; also elsewhere on the board
ENCODER8_B: J8.18, J9.18, SW25.B; also elsewhere on the board
ENCODER8_SW: J8.26, J9.26, SW25.S1; also elsewhere on the board
GND: J1.3, J2.1, J3.2, J4.5, J5.14, J8.43, J8.44, J8.45, J9.43, J9.44, J9.45, Q1.2 (E), SW1.1, SW2.1, SW3.1, SW4.1, SW5.C, SW5.MP, SW5.S2, SW6.C, SW6.MP, SW6.S2, SW7.C, SW7.MP, SW7.S1, SW7.S2, SW8.1, SW9.1, SW10.1, SW11.1, SW12.1, SW13.1, SW14.1, SW15.1, SW16.1, SW17.1, SW18.1, SW19.1, SW20.C, SW20.MP, SW20.S2, SW21.C, SW21.MP, SW21.S2, SW22.C, SW22.MP, SW22.S2, SW23.C, SW23.MP, SW23.S2, SW24.C, SW24.MP, SW24.S2, SW25.C, SW25.MP, SW25.S2; also elsewhere on the board
HP_L: J1.1; also elsewhere on the board
HP_R: J1.2; also elsewhere on the board
LCD_CLK: J2.5; also elsewhere on the board
LCD_CS1: J2.3; also elsewhere on the board
LCD_CS2: J2.4; also elsewhere on the board
LCD_MISO: J2.6; also elsewhere on the board
LCD_MOSI: J2.7; also elsewhere on the board
MAIN_BOOT: J5.2; also elsewhere on the board
MAIN_LM: J3.13
MAIN_LP: J3.12
MAIN_OUT_L_M: J4.2; also elsewhere on the board
MAIN_OUT_L_P: J4.1, JP3.2 (B)
MAIN_OUT_R_M: J4.4; also elsewhere on the board
MAIN_OUT_R_P: J4.3, JP4.1 (A)
MAIN_RESET: J5.1; also elsewhere on the board
MAIN_RM: J3.11
MAIN_RP: J3.10
MAIN_SWDCLK: J5.3; also elsewhere on the board
MAIN_SWDIO: J5.4; also elsewhere on the board
MOD_SCL: J3.4; also elsewhere on the board
MOD_SDA: J3.5; also elsewhere on the board
OUT_L_PRE: JP3.1 (A); also elsewhere on the board
OUT_R_PRE: JP4.2 (B); also elsewhere on the board
PERIPHERAL_BOOT: J5.6; also elsewhere on the board
PERIPHERAL_RESET: J5.5; also elsewhere on the board
PERIPHERAL_SWDCLK: J5.7; also elsewhere on the board
PERIPHERAL_SWDIO: J5.8; also elsewhere on the board
READY: J3.3
SCRUBBER_A: J8.1, J9.1, SW7.A; also elsewhere on the board
SCRUBBER_B: J8.2, J9.2, SW7.B; also elsewhere on the board

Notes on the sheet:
Main output
Headphone output
Hidden debug header
Both screens will be a 3.5" TFT LCD with a ILI9485 controller on SPI Mode Touchscreen will not be used
Peripherals

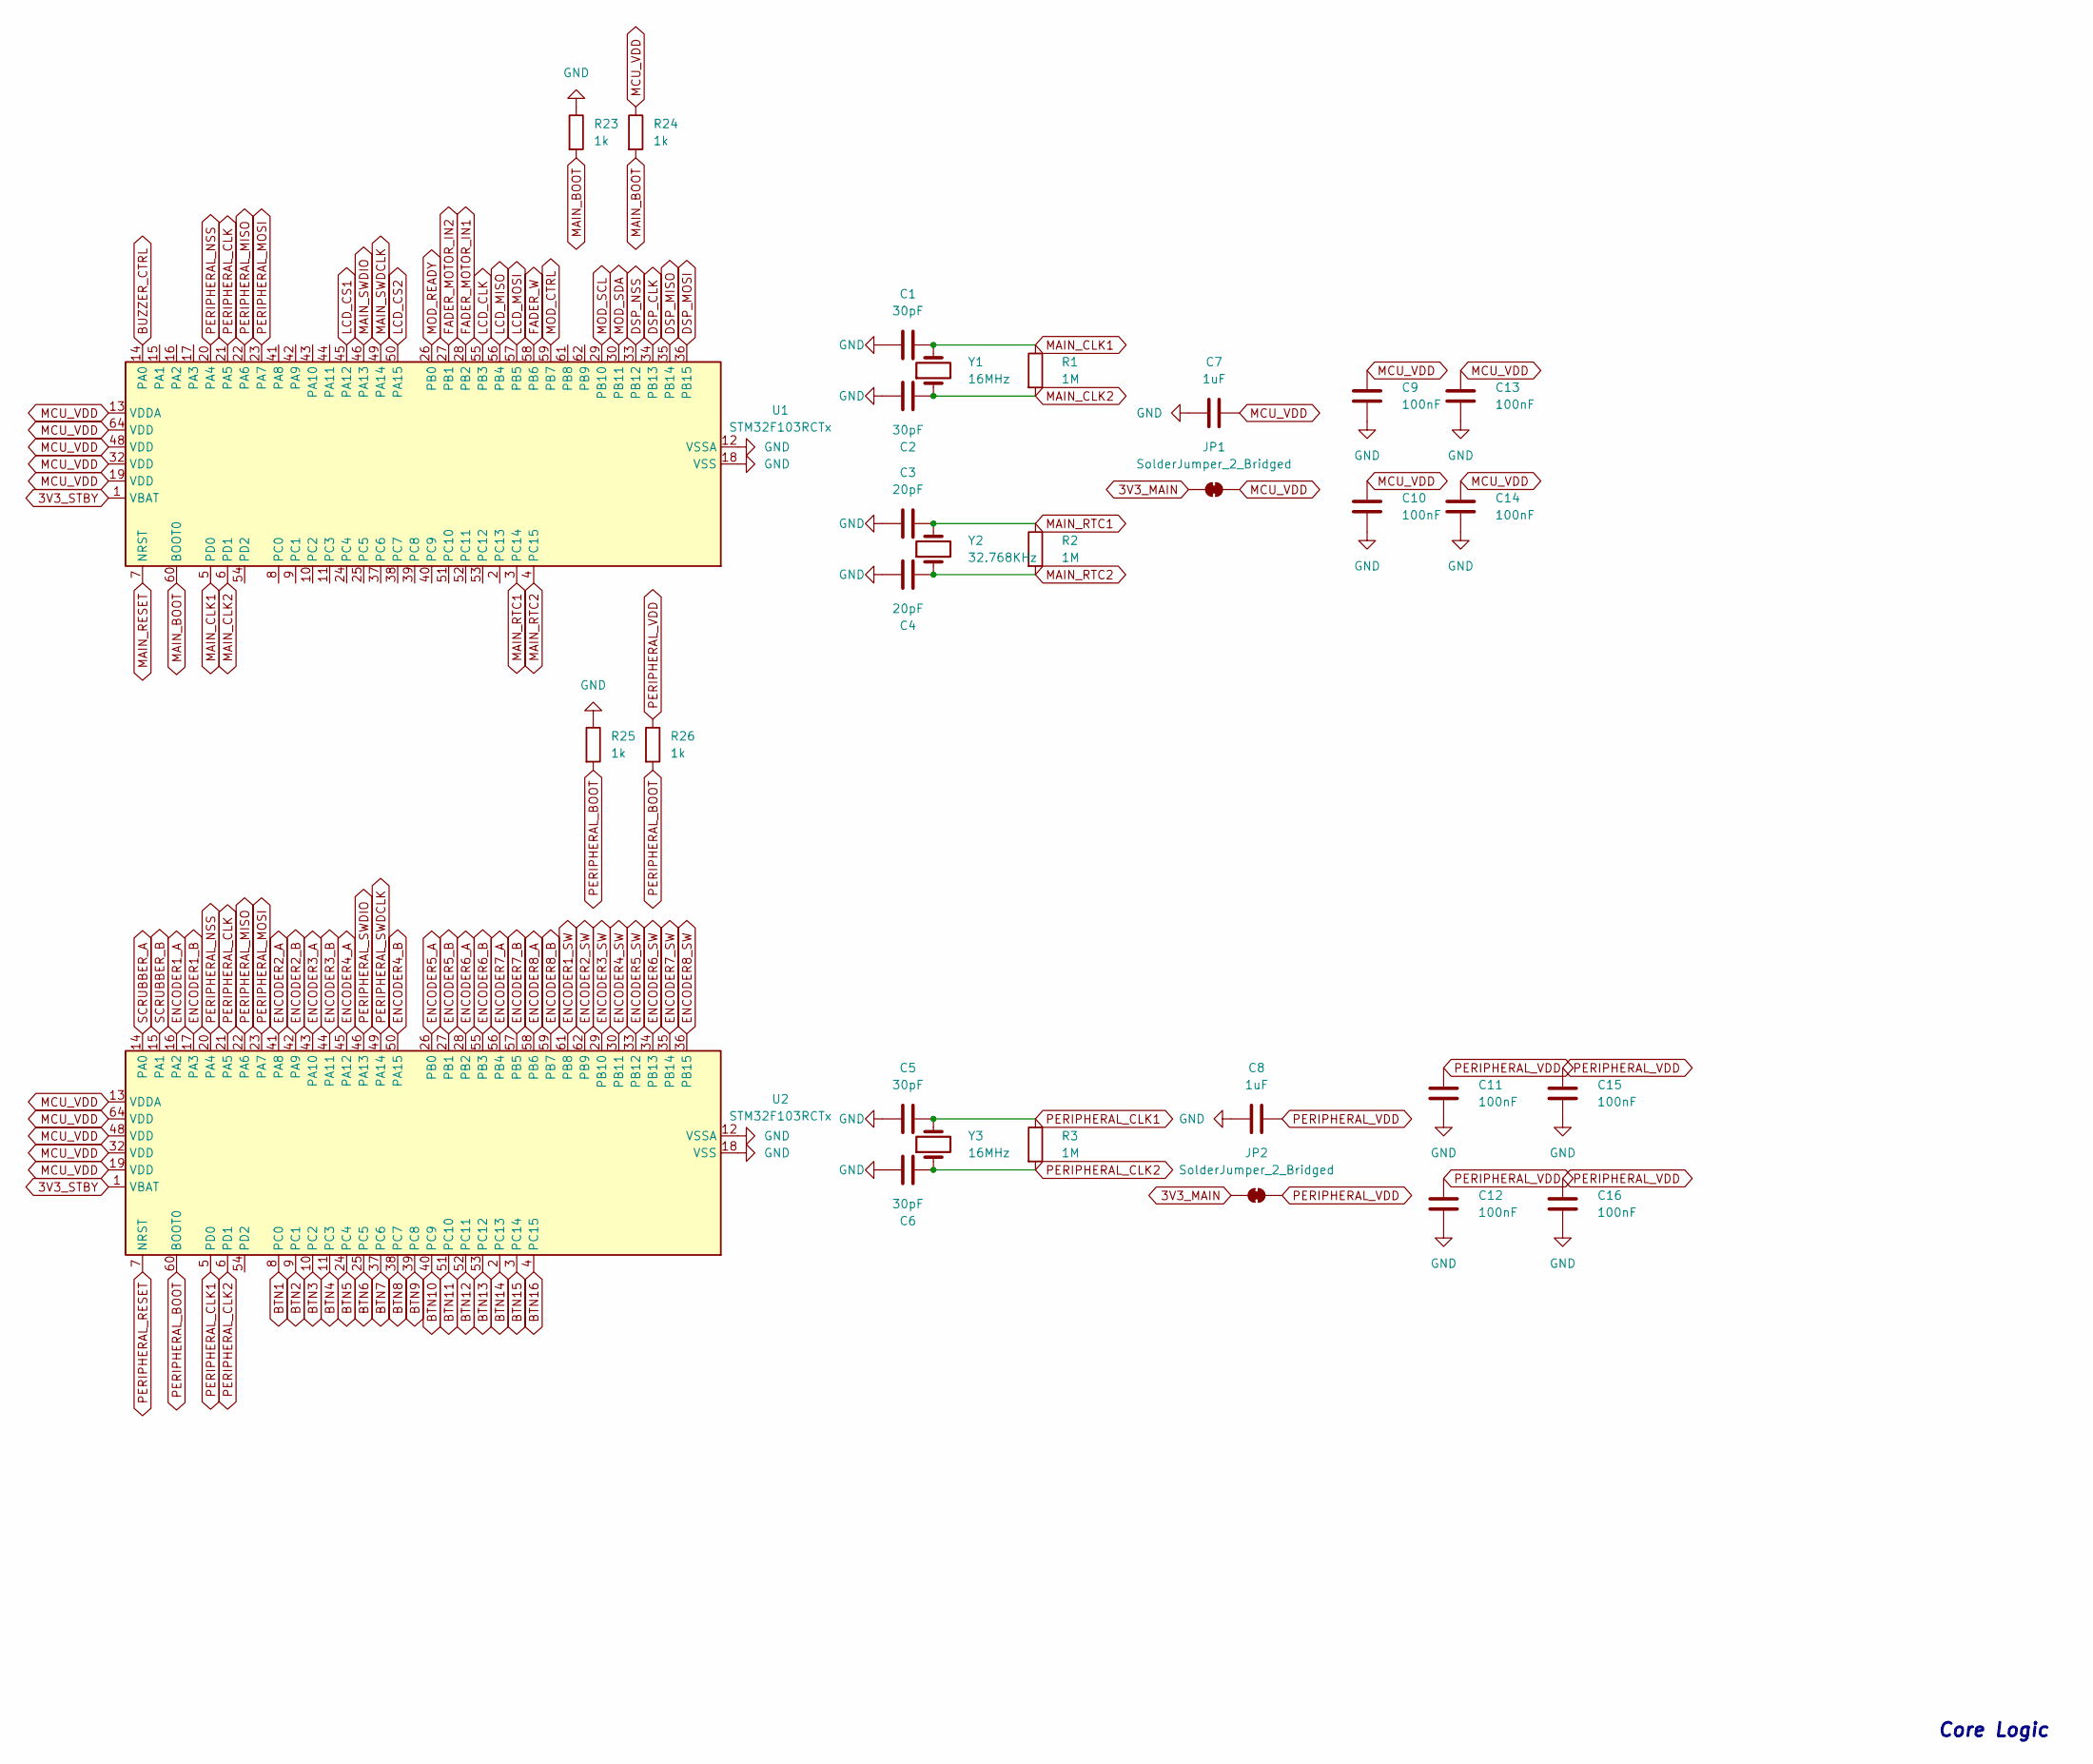
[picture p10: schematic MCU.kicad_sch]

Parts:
C1, C2, C5, C6: 30pF; C_0603_1608Metric
C3, C4: 20pF; C_0603_1608Metric
C7, C8: 1uF; C_0603_1608Metric
C9, C10, C11, C12, C13, C14, C15, C16: 100nF; C_0603_1608Metric
JP1, JP2: SolderJumper_2_Bridged; SolderJumper-2_P1.3mm_Bridged2Bar_Pad1.0x1.5mm
R1, R2, R3: 1M; R_0603_1608Metric
R23, R24, R25, R26: 1k; R_0603_1608Metric
U1, U2: STM32F103RCTx; LQFP-64_10x10mm_P0.5mm
Y1, Y3: 16MHz; Crystal_HC49-U_Vertical
Y2: 32.768KHz; Crystal_HC49-U_Vertical

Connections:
3V3_MAIN: JP1.1 (A), JP2.1 (A); also elsewhere on the board
3V3_STBY: U1.1 (VBAT), U2.1 (VBAT); also elsewhere on the board
BTN1: U2.8 (PC0); also elsewhere on the board
BTN2: U2.9 (PC1); also elsewhere on the board
BTN3: U2.10 (PC2); also elsewhere on the board
BTN4: U2.11 (PC3); also elsewhere on the board
BTN5: U2.24 (PC4); also elsewhere on the board
BTN6: U2.25 (PC5); also elsewhere on the board
BTN7: U2.37 (PC6); also elsewhere on the board
BTN8: U2.38 (PC7); also elsewhere on the board
BTN9: U2.39 (PC8); also elsewhere on the board
BTN10: U2.40 (PC9); also elsewhere on the board
BTN11: U2.51 (PC10); also elsewhere on the board
BTN12: U2.52 (PC11); also elsewhere on the board
BTN13: U2.53 (PC12); also elsewhere on the board
BTN14: U2.2 (PC13); also elsewhere on the board
BTN15: U2.3 (PC14); also elsewhere on the board
BTN16: U2.4 (PC15); also elsewhere on the board
BUZZER_CTRL: U1.14 (PA0); also elsewhere on the board
DSP_CLK: U1.34 (PB13)
DSP_MISO: U1.35 (PB14)
DSP_MOSI: U1.36 (PB15)
DSP_NSS: U1.33 (PB12)
ENCODER1_A: U2.16 (PA2); also elsewhere on the board
ENCODER1_B: U2.17 (PA3); also elsewhere on the board
ENCODER1_SW: U2.61 (PB8); also elsewhere on the board
ENCODER2_A: U2.41 (PA8); also elsewhere on the board
ENCODER2_B: U2.42 (PA9); also elsewhere on the board
ENCODER2_SW: U2.62 (PB9); also elsewhere on the board
ENCODER3_A: U2.43 (PA10); also elsewhere on the board
ENCODER3_B: U2.44 (PA11); also elsewhere on the board
ENCODER3_SW: U2.29 (PB10); also elsewhere on the board
ENCODER4_A: U2.45 (PA12); also elsewhere on the board
ENCODER4_B: U2.50 (PA15); also elsewhere on the board
ENCODER4_SW: U2.30 (PB11); also elsewhere on the board
ENCODER5_A: U2.26 (PB0); also elsewhere on the board
ENCODER5_B: U2.27 (PB1); also elsewhere on the board
ENCODER5_SW: U2.33 (PB12); also elsewhere on the board
ENCODER6_A: U2.28 (PB2); also elsewhere on the board
ENCODER6_B: U2.55 (PB3); also elsewhere on the board
ENCODER6_SW: U2.34 (PB13); also elsewhere on the board
ENCODER7_A: U2.56 (PB4); also elsewhere on the board
ENCODER7_B: U2.57 (PB5); also elsewhere on the board
ENCODER7_SW: U2.35 (PB14); also elsewhere on the board
ENCODER8_A: U2.58 (PB6); also elsewhere on the board
ENCODER8_B: U2.59 (PB7); also elsewhere on the board
ENCODER8_SW: U2.36 (PB15); also elsewhere on the board
FADER_MOTOR_IN1: U1.28 (PB2); also elsewhere on the board
FADER_MOTOR_IN2: U1.27 (PB1); also elsewhere on the board
FADER_W: U1.58 (PB6); also elsewhere on the board
GND: C1.2, C2.2, C3.2, C4.2, C5.2, C6.2, C7.1, C8.1, C9.2, C10.2, C11.2, C12.2, C13.2, C14.2, C15.2, C16.2, R23.1, R25.1, U1.12 (VSSA), U1.18 (VSS), U1.31 (VSS), U1.47 (VSS), U1.63 (VSS), U2.12 (VSSA), U2.18 (VSS), U2.31 (VSS), U2.47 (VSS), U2.63 (VSS); also elsewhere on the board
LCD_CLK: U1.55 (PB3); also elsewhere on the board
LCD_CS1: U1.45 (PA12); also elsewhere on the board
LCD_CS2: U1.50 (PA15); also elsewhere on the board
LCD_MISO: U1.56 (PB4); also elsewhere on the board
LCD_MOSI: U1.57 (PB5); also elsewhere on the board
MAIN_BOOT: R23.2, R24.2, U1.60 (BOOT0); also elsewhere on the board
MAIN_CLK1: C1.1, R1.1, U1.5 (PD0), Y1.2
MAIN_CLK2: C2.1, R1.2, U1.6 (PD1), Y1.1
MAIN_RESET: U1.7 (NRST); also elsewhere on the board
MAIN_RTC1: C3.1, R2.1, U1.3 (PC14), Y2.2
MAIN_RTC2: C4.1, R2.2, U1.4 (PC15), Y2.1
MAIN_SWDCLK: U1.49 (PA14); also elsewhere on the board
MAIN_SWDIO: U1.46 (PA13); also elsewhere on the board
MCU_VDD: C7.2, C9.1, C10.1, C13.1, C14.1, JP1.2 (B), R24.1, U1.13 (VDDA), U1.19 (VDD), U1.32 (VDD), U1.48 (VDD), U1.64 (VDD), U2.13 (VDDA), U2.19 (VDD), U2.32 (VDD), U2.48 (VDD), U2.64 (VDD)
MOD_CTRL: U1.59 (PB7); also elsewhere on the board
MOD_READY: U1.26 (PB0)
MOD_SCL: U1.29 (PB10); also elsewhere on the board
MOD_SDA: U1.30 (PB11); also elsewhere on the board
PERIPHERAL_BOOT: R25.2, R26.2, U2.60 (BOOT0); also elsewhere on the board
PERIPHERAL_CLK: U1.21 (PA5), U2.21 (PA5)
PERIPHERAL_CLK1: C5.1, R3.1, U2.5 (PD0), Y3.2
PERIPHERAL_CLK2: C6.1, R3.2, U2.6 (PD1), Y3.1
PERIPHERAL_MISO: U1.22 (PA6), U2.22 (PA6)
PERIPHERAL_MOSI: U1.23 (PA7), U2.23 (PA7)
PERIPHERAL_NSS: U1.20 (PA4), U2.20 (PA4)
PERIPHERAL_RESET: U2.7 (NRST); also elsewhere on the board
PERIPHERAL_SWDCLK: U2.49 (PA14); also elsewhere on the board
PERIPHERAL_SWDIO: U2.46 (PA13); also elsewhere on the board
PERIPHERAL_VDD: C8.2, C11.1, C12.1, C15.1, C16.1, JP2.2 (B), R26.1
SCRUBBER_A: U2.14 (PA0); also elsewhere on the board
SCRUBBER_B: U2.15 (PA1); also elsewhere on the board

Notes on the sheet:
Core Logic

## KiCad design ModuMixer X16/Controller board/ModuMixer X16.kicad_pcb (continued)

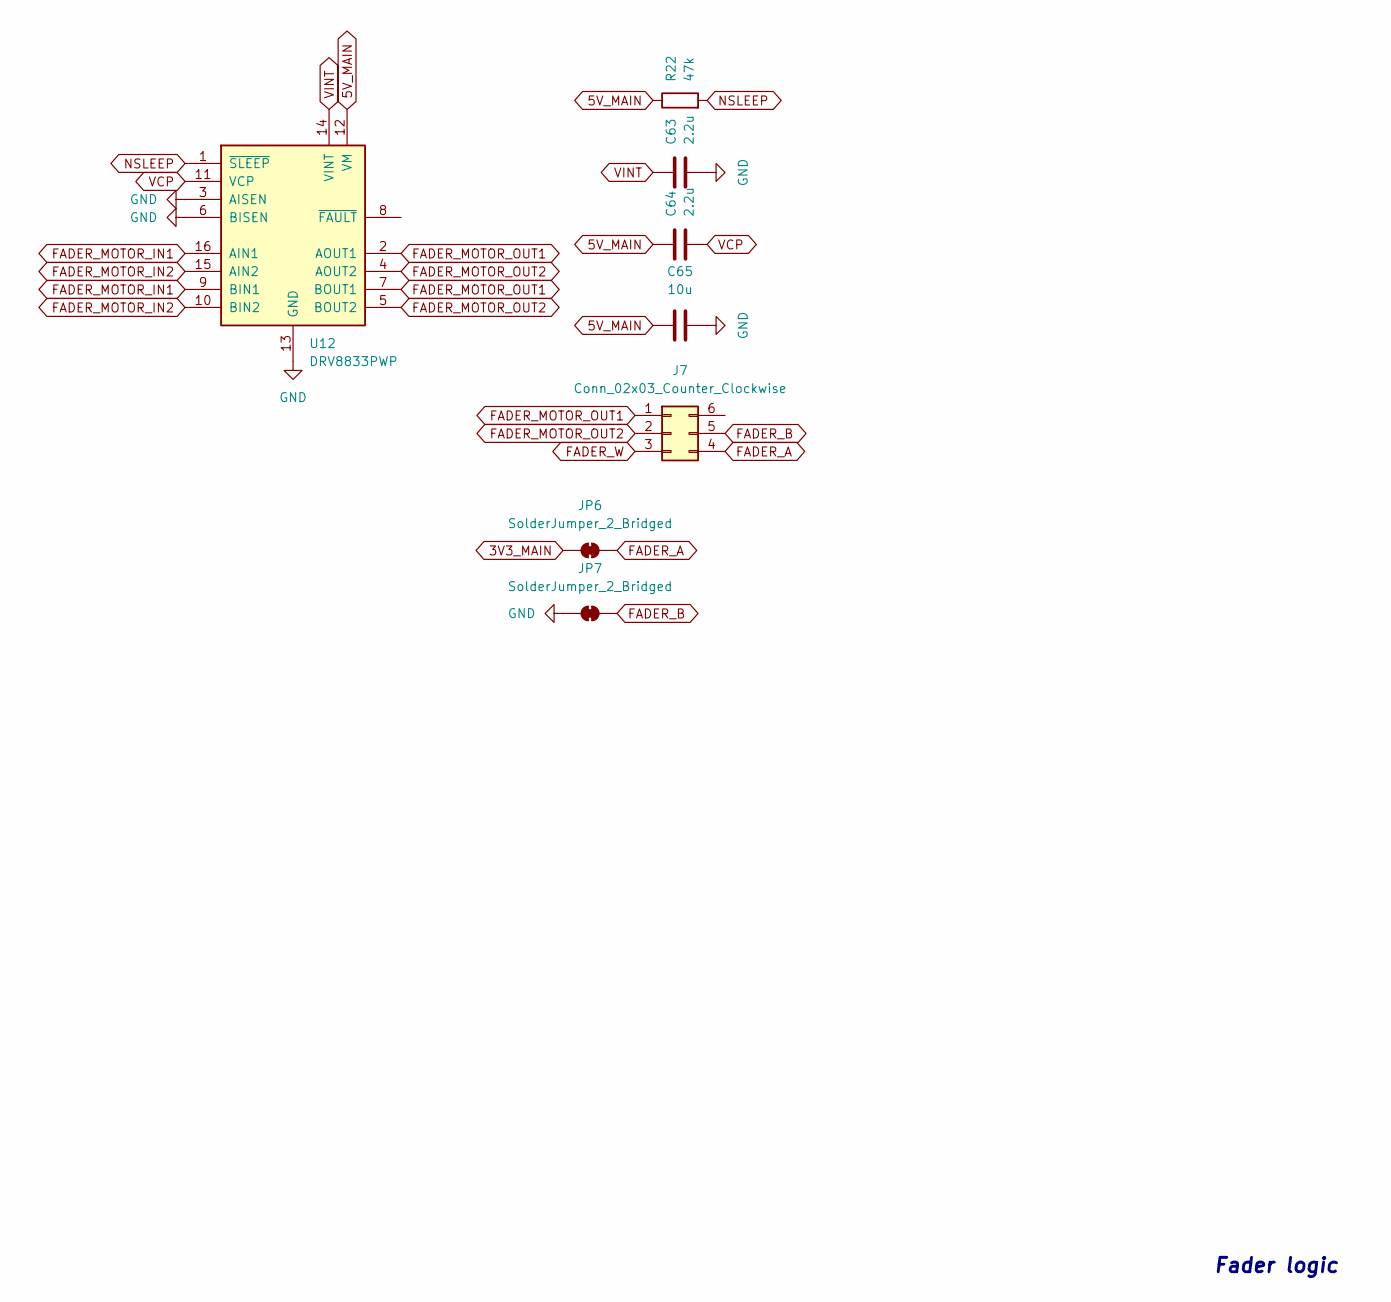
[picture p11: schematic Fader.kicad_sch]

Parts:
C63, C64: 2.2u; C_0603_1608Metric
C65: 10u; C_0603_1608Metric
J7: Conn_02x03_Counter_Clockwise; PinHeader_2x03_P2.54mm_Vertical
JP6, JP7: SolderJumper_2_Bridged; SolderJumper-2_P1.3mm_Bridged2Bar_Pad1.0x1.5mm
R22: 47k; R_0603_1608Metric
U12: DRV8833PWP; HTSSOP-16-1EP_4.4x5mm_P0.65mm_EP3.4x5mm_Mask2.46x2.31mm_The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

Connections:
3V3_MAIN: JP6.1 (A); also elsewhere on the board
5V_MAIN: C64.1, C65.1, R22.1, U12.12 (VM); also elsewhere on the board
FADER_A: J7.4, JP6.2 (B)
FADER_B: J7.5, JP7.2 (B)
FADER_MOTOR_IN1: U12.9 (BIN1), U12.16 (AIN1); also elsewhere on the board
FADER_MOTOR_IN2: U12.10 (BIN2), U12.15 (AIN2); also elsewhere on the board
FADER_MOTOR_OUT1: J7.1, U12.2 (AOUT1), U12.7 (BOUT1)
FADER_MOTOR_OUT2: J7.2, U12.4 (AOUT2), U12.5 (BOUT2)
FADER_W: J7.3; also elsewhere on the board
GND: C63.2, C65.2, JP7.1 (A), U12.3 (AISEN), U12.6 (BISEN), U12.13 (GND), U12.17 (GND); also elsewhere on the board
NSLEEP: R22.2, U12.1 (~SLEEP)
VCP: C64.2, U12.11 (VCP)
VINT: C63.1, U12.14 (VINT)

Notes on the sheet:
Fader logic

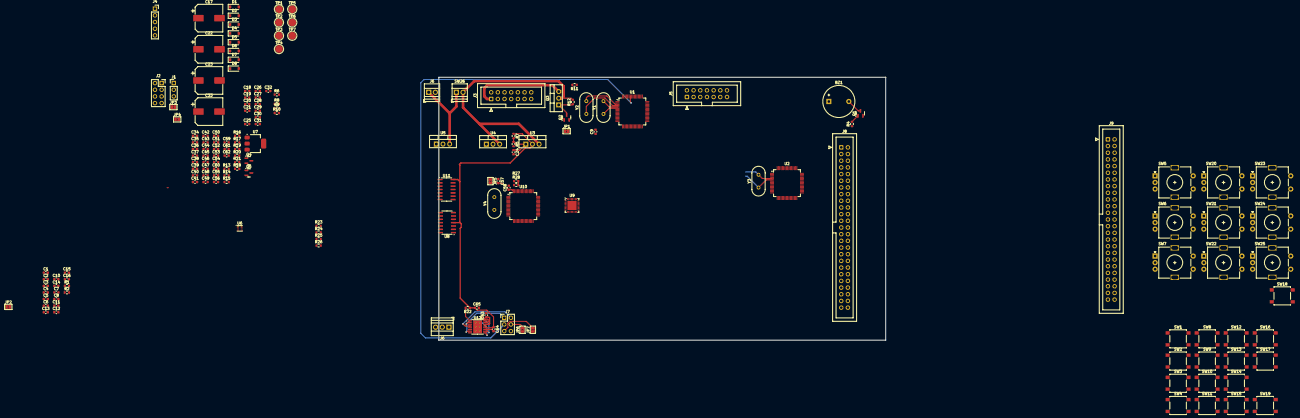
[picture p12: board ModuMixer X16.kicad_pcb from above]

Board: 2 copper layers, 170.0 x 100.0 mm, 173 parts (1 on the bottom side), 137 nets.

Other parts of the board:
J6#2: Screw_Terminal_01x03; TerminalBlock_Xinya_XY308-2.54-3P_1x03_P2.54mm_Horizontal
TP3: 5V_MAIN; TestPoint_Pad_D3.0mm
TP4: 3V3_MAIN; TestPoint_Pad_D3.0mm
TP5: 3V3_STBY; TestPoint_Pad_D3.0mm
TP7: 3V3_ALW; TestPoint_Pad_D3.0mm

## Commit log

2024-07-31 Upload project files
    [DSP.kicad_sch, Fader.kicad_sch, MCU.kicad_sch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]
2024-08-01 update idk
    [DSP.kicad_sch, Fader.kicad_sch, Peripherals.kicad_sch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]
2024-08-01 idk testing github desktop
    [DSP.kicad_sch, ModuMixer X16.kicad_sch]
2024-08-01 Connected DSP to Main
    Connected SPI Data lines from main (master) MCU to DSP (slave) MCU
    [MCU.kicad_sch]
2024-08-01 Added input modules
    [Connectors.kicad_sch, Core Logic.kicad_sch, Fader.kicad_sch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]
2024-08-02 Starting work on output modules
    tomorrow i'll be making the output modules i guess
    [Output module.kicad_pcb, Output module.kicad_sch, connectors.kicad_sch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]
2024-08-11 Added schematics pdf
    [Core Logic.kicad_sch, Input Module.kicad_sch, ModuMixer X16.kicad_sch]
2024-08-24 Switching microcontrollers
    Midway through switching all microcontrollers in the project to STM32F103RC due to price constraints
    [DSP.kicad_sch, MCU.kicad_sch, Peripherals.kicad_sch]
2024-08-24 Midway through MCU change
    [MCU.kicad_sch, Peripherals.kicad_sch]
2024-08-28 Midway through MCU replacement
    Sometimes i feel like it would be better to start over considering it's a digital mixer.
    The only thing left is doing the DSP connections and calculating the values for a 16mhz crystal on all 3 MCUs
    [DSP.kicad_sch, Fader.kicad_sch, MCU.kicad_sch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]
2024-08-28 MCU replacement done
    I finally did everything (i guess), i replaced the MCUs, set the clock components, connected them, idk i guess it's ok now, we just gotta make that pcb
    [DSP.kicad_sch, MCU.kicad_sch, Peripherals.kicad_sch]
2024-08-29 asdasgashg
    sfjhadgdjasdg
    [DSP.kicad_sch, Fader.kicad_sch, MCU.kicad_sch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]
2024-08-29 Changed all labels to global
    I made it in a rather hacky way (editing all files on notepad with Ctrl + H), i'm only reverting this if something breaks
    [DSP.kicad_sch, Fader.kicad_sch, MCU.kicad_sch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]
2024-08-31 MCU replacement finished
    [Connectors.kicad_sch, Core Logic.kicad_sch, DSP.kicad_sch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]
